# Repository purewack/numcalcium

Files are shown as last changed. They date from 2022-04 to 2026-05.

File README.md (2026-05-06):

# NumCalcium

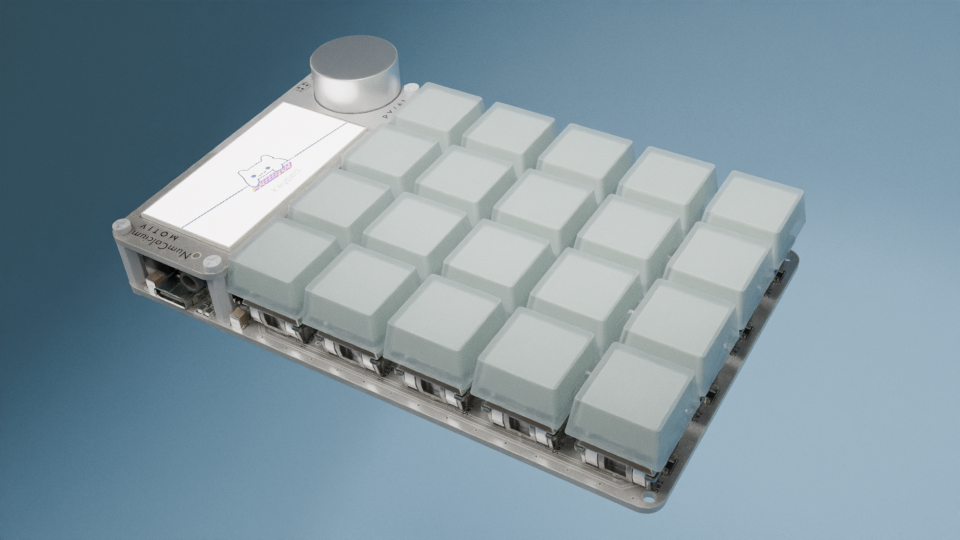
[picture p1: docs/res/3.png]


NumCalcium is a calculator-like USB + Bluetooth Numpad keyboard. This is the primary intended function, however, because it is powered by MicroPython, users are able to write their own programs for it.
There were a number of different hardware and software revision before I settled on a combination of an ESP32 S3 and MicroPython. It made so much sense for the applications that I wanted to achieve, and was far easier to get working than my previous attempts with STM32F103 and a custom system in C, more about the development history below if you're interested :)

## Installation

You can download the release binary and flash it using esptool.py or other compatible ESP32 flashing tools.
You can also build the sources and / or change any config here to suit your needs, then flash the resulting binary.

The recommended method is to use the Makefile in this repo, which in turn uses `Docker` to pull the specific `esp-idf` version to build `MicroPython` against.

Hold down the encoder button (ESP32 GP0 pin) and reset the device, then:

```bash
make gen-ulp all deploy
```

## Hardware

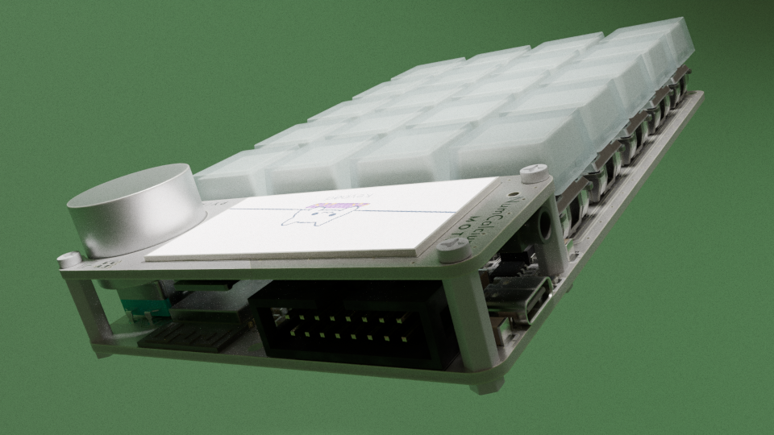
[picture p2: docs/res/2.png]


The hardware contains an ESP32 S3 module with integrated PSRAM, a color LCD (320*170 px, ST7789), a rotary encoder, 20 mechanical switch buttons, SD card slot, USB (2.0) C port, Headphone jack, a buzzer, and exposed GPIO using an IDC connector.

### Pinout
The IDC connector can be used to plug in external hardware in three ways:
- using jumper wires onto a breadboard
- using a dedicated IDC cable 
- using the port to plug in custom PCBs

The last option is encouraged to develop standalone daughter boards with your custom hardware, including driver code, which can be stored on a flash chip located on the daughter board, and have NumCalcium read it and execute the code!

```
BACK VIEW - TOP

                TOP OF IDC CONNECTOR
[GND,   VBAT,   SDA/TX1, SCL/RX1, TX0,  RX0, GND, VCC]
[GP8,   GP7,    GP6,     GP5,     GP4,  GP3, GP2, GP1]

BACK VIEW - BOTTOM OF BOARD
```

The rotary encoder button is connected to GP0, which allows entering flash mode for firmware updates. The button is also monitored and treated separately from the keys as this button is intended to return to the main app switcher, [described in detail on its own repo.](https://github.com/purewack/numcalcium-apps.git)

The device has a built in li-ion battery charger and voltage regulator, so you can power the whole unit off a 18650 cell, and charge it while using it. The regulator + charger combo has been configured in such a way to provide enough current for charging and system demands.

There is an additional low power regulator designed to be always on, to keep the ESP32 powered during deep-sleep. The ESP32 can control the main regulator and turn it off to power down all other components on the board, except itself. By doing this, the board can have peripherals plugged in to the IDC port, but they will not drain the battery, as the regulator will disable VCC and another transistor will cut VBAT to the IDC port, which normally would be connected directly to the 18650 cell.

<ins>**Warning:**</ins>

The VBAT, as mentioned above, is connected to the positive terminal of the 18650 battery cell through a MOSFET, no other protection is provided from shorting the pin to ground, so caution must be taken as these cells can discharge a lot of current at once very quickly, most likely damaging the transistor before any real harm is done elsewhere, regardless caution is to be taken when operating near this pin!

The headphone jack is connected to the ESP32 via stereo RC filters, for crude PDM audio, which is experimental as the performance hit of the MicroPython interpreter has an impact on the scheduling of audio buffers at the time of writing.

The buzzer is a piezo element which can be used for 'beeps and boops' for feedback purposes when writing your own apps. Its also quite good at playing chiptunes ;)

The SD card slot and LCD screen are on the same SPI bus so it is advised to write code around this limitation in mind, avoiding using threads to address the screen and card at the same time to avoid data corruption and unwanted side effects.

The LCD is connected to SPI3 Bus, leaving SPI2 available to users on the IDC port.

The IDC port exposes two UART pairs, and I2C pins on the same pins which are used by 'cartridge' PCB featuring flash chips with driver code, allowing the board to setup the pins and further communication as needed.
The RX0 TX0 pair is permanently mapped to output `stdout` for developing applications which use USB, allowing users to still see debugging output on their console using UART converters.

There are addressable LEDs under each key and on the front next to the LCD. with give more options for UI UX design by for example highlighting keys that do something in a certain mode.

## Software

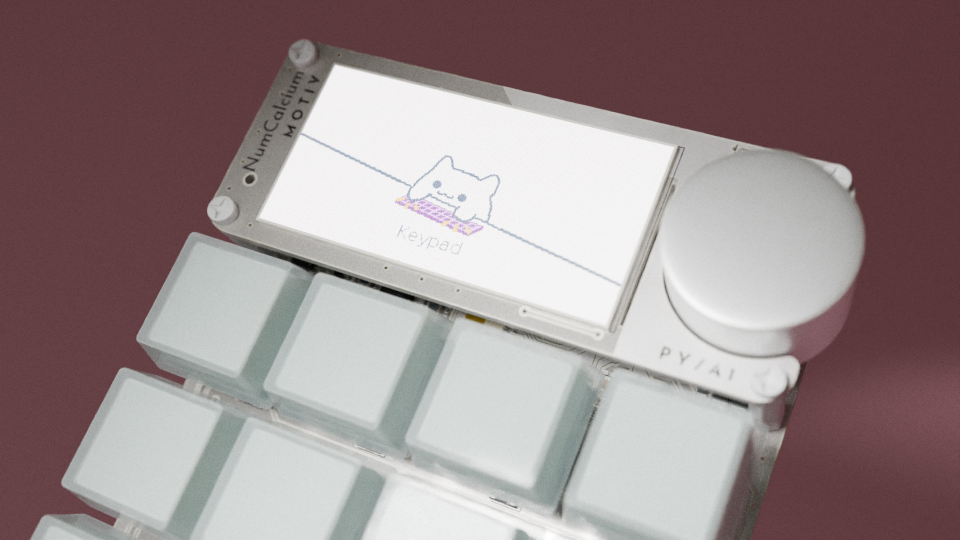
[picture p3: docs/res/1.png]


The main module which bundles all new and useful functionality compared to base MicroPython is `numcalc`.

This module contains classes making setting up common operations and pin assignments easier, specifically:
- interacting with the LCD
- LCD backlight adjustment
- a class specifically configuring the SD card slot
- buzzer tone control, 
- keypad input reading
- encoder turns and clicks
- LED control by obfuscating the neopixel class setup
- cartridge code loading and burning
- headphone PDM buffered audio streaming
- lcd BMP image parsing, framebuffer ready

> [class LCD() docs](docs/lcd.md)

> [class Keys() docs](docs/keys.md)

> [other `numcalc` functions docs](docs/other.md)

## Build and development

- Build and flash main firmware:

        make all
        make deploy

- Build and flash firmware with no modules, just c drivers:

        make firmware-no-freeze
        make deploy-no-freeze

- Build ULP code:

        make gen-ulp

- Build font file:
        make gen-font

- Update pin definitions:
        make gen-pins

# Devlog

I have included a development history going back through different [hardware designs and software paradigms.](devlog/HISTORY.md)

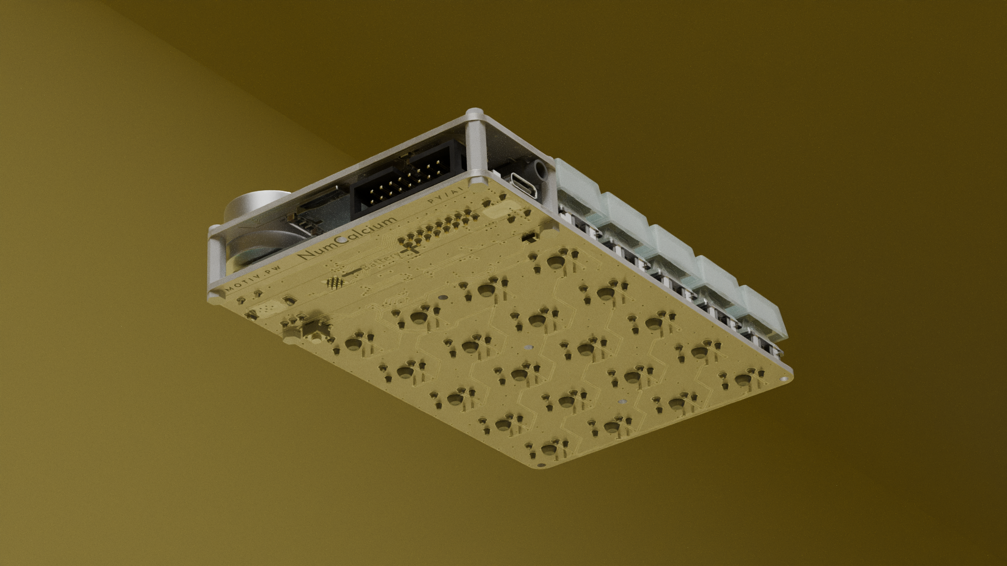
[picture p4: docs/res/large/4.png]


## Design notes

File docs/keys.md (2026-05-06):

# Keys Class Reference

The `Keys` class in `software-pya1/modules/__keys.py` provides access to the Numcalcium button matrix and encoder input. It is backed by an ESP32 ULP program that scans keys continuously, including during deep sleep, and stores press/release events in buffered state registers.

## Hardware

The keys are divided into groups of 3, reading from bottom to top and from left to right, giving 7 groups, with the last one having 2 keys.

The ULP manages the input and output states of only 4 pins to read 20 keys, multiplexing pin functions to drive a shift register on board driving each group one by one and reading each group state, accumulating results over the scanning period and placing the results in the buffered register, which the Keys class has access to via `mem32`.

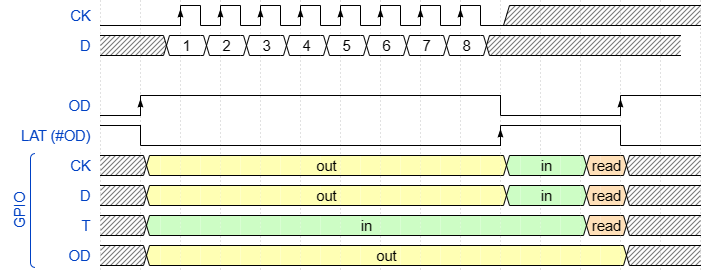
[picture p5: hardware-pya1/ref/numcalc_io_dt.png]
io timing


## Overview

- The ULP scans all physical keys and the rotary encoder.
- Key press and release events are buffered until explicitly cleared.
- Encoder turns and the encoder "home" click are also managed by the ULP.
- Raw read methods return current hardware state without clearing buffered events.

## Key encoding and mapping

Keys are represented as bits within a 20-bit integer.

- Each key corresponds to one bit.
- Bits are ordered from bottom-to-top, left-to-right.
- A set bit indicates the key has been pressed or released, depending on the buffer.

The class exposes named key constants, for example:

- `Keys.SHIFT`
- `Keys.DOT`
- `Keys.N0` through `Keys.N9`
- `Keys.F1`, `Keys.F2`, `Keys.F3`
- `Keys.A`, `Keys.B`, `Keys.C`, `Keys.D`, `Keys.E`

Alias names are also available for readability:

- `Keys.KEY_SHIFT`
- `Keys.KEY_DOT`
- `Keys.KEY_0` through `Keys.KEY_9`
- `Keys.KEY_F1`, `Keys.KEY_F2`, `Keys.KEY_F3`
- `Keys.KEY_SIDE_A` through `Keys.KEY_SIDE_E`

## ULP-managed buffering

The ULP keeps two buffered registers:

- `bdown` stores keys that have been pressed down.
- `bup` stores keys that have been released.

Buffer state is preserved across normal operation and deep sleep, allowing the application to read events later without missing input.

### Down and up queries

- `keys.isDown(key, reset=False)` returns whether the specified key is recorded as down.
- `keys.isUp(key, reset=False)` returns whether the specified key is recorded as up.

Both methods support an optional `reset=True` to clear the buffer bit for that key.

### Batch reads

- `keys.getAllDown()` returns a list of all keys currently buffered as down, then clears that buffer.
- `keys.getAllUp()` returns a list of all keys currently buffered as up, then clears that buffer.
- `keys.getNextDown()` returns the next buffered down key and clears it.
- `keys.getNextUp()` returns the next buffered up key and clears it.

### Clearing

- `keys.clearDown(key)` clears a single down bit.
- `keys.clearUp(key)` clears a single up bit.
- `keys.clearAllDown()` clears all down events.
- `keys.clearAllUp()` clears all up events.
- `keys.clearAll()` clears both up/down buffers and resets turn counts.

## Encoder support

Encoder movement and clicks are handled by the same ULP process.

- `keys.raw_turns()` returns the current raw encoder turn count.
- `keys.turns(invert=False)` reads and clears the turn counter.
- `keys.raw_home()` returns the current raw encoder click state.

### Home button behavior

The encoder click is treated specially as a "home" button, because its primary role is to return to the app launcher.

- `keys.shouldHome(value=None)` reads or writes the buffered home request flag.
- `keys.wasHomeRequested()` returns `True` if the home button was pressed, and clears the buffered state.

The internal `bhome` register is used to preserve the encoder click state until the main application consumes it.

## Raw state access

Raw read methods allow polling of the current hardware state without affecting buffered event registers:

- `keys.raw()` returns the current scanned key matrix value from `bscan`.
- `keys.raw_home()` returns the raw encoder click state.
- `keys.raw_turns()` returns the current encoder turn count.

These raw methods are useful for diagnostics and immediate state monitoring while keeping buffered press/release history intact.

## Initialization and driver loading

When a `Keys` object is constructed, it:

1. creates an `esp32.ULP_RV()` instance,
2. loads the ULP binary from `__ulpio`, and
3. starts the ULP program.

An optional scan period may be provided to `Keys(period)` to adjust the ULP wakeup interval.

## Example Usage

```python
from __keys import Keys

keys = Keys()

if keys.isDown(Keys.KEY_1, reset=True):
    print("Key 1 pressed")

turns = keys.turns()
if turns != 0:
    print("Encoder moved", turns)

if keys.wasHomeRequested():
    print("Home button clicked")

print("raw key bits", hex(keys.raw()))
```

## Notes

- The ULP scans keys even while the main CPU is asleep, making input reliable across sleep cycles.
- Press/release events are buffered independently from raw state reads.
- The encoder click is buffered as a home event rather than a normal key event.
- Clearing buffered values is explicit; raw reads do not consume events.

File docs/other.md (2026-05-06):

# Other Numcalcium Module Features

This document covers the remaining minor `numcalc` module components: module-level control functions, the `DAC` helper class, LED helpers, and the `Battery` utility.

## Top-Level Control Functions

### `shutdown()`

Shuts down the device cleanly by:

- clearing all NeoPixel LEDs with `clearLeds()`
- entering low-power sleep via `__sleep.enterLowPowerSleep()`

This is the recommended way to put the device into deep power-save mode.

### `runFromCartridge()`

Runs code stored on the external cartridge by delegating to `__cartridge.run()`.

### `burnToCartridge(data)`

Writes `data` to the cartridge using `__cartridge.burn(data)` and then verifies the burn with `__cartridge.check()`.

If the check fails, it raises an exception:

```python
raise Exception('Error during burning, check wiring and chip')
```

## `DAC` Class

The `DAC` class in `software-pya1/modules/numcalc.py` is a thin wrapper around the board-specific audio DAC implementation.

```python
class DAC(_board.DAC):
    pass
```

On this board, the actual audio driver is implemented in C in `software-pya1/cmodules/board_dac.c`.
That module exposes a Sigma-Delta audio class that is used by `_board.DAC`, so `numcalc.DAC` is effectively the Python entry point to the native audio driver.

### Board C module details

- The C implementation lives in `software-pya1/cmodules/board_dac.c`.
- It defines a `SigmaDelta` type with a constructor that accepts a buffer, a callback, and optional output pin configuration.
- The C driver supports single or dual buffer audio streaming and schedules callbacks when half or all samples have been consumed.
- It exposes `deinit()`, `pause()`, and `resume()` methods for managing playback.

### Typical usage

Examples in the repository show audio playback using `numcalc.DAC` with a buffer and a callback:

```python
import numcalc

sdm = numcalc.DAC(buffer_a, buffer_callback)
```

or with explicit output pins:

```python
sdm = numcalc.DAC(buffer_a, buffer_callback, [machine.Pin.board.A_OUT_L, machine.Pin.board.A_OUT_R])
```

A tuple of two buffers may also be passed for ping-pong streaming.

## LED Helper Functions

The module exposes simple NeoPixel-based LED control helpers backed by a `NeoPixel` object attached to `machine.Pin.board.LEDS`.

### `clearLeds()`

Turns all LEDs off and writes the change immediately.

### `statusLed(r, g, b)`

Sets LED index `0` to the provided RGB color and updates the strip.

This is usually used for a status indicator separate from the key LEDs.

### `led(keyNumber, r, g, b)`

Sets the LED for a given key index.

- `keyNumber` is mapped to NeoPixel index `keyNumber + 1`
- the first LED (`index 0`) is reserved for status

Example:

```python
numcalc.led(3, 255, 0, 0)
```

## `Battery` Class

The `Battery` class provides information about the battery and USB charge state.

### Initialization

On construction, `Battery()` initializes:

- `self.vbat` as an ADC on `machine.Pin.board.VBAT_MON`
- `self.vbus` as the charge-state pin `machine.Pin.board.CHR_STATE`
- `self.DIFF_THRESH = 0.05`

### `present()`

Returns `True` when a valid battery voltage is present.

In practice, it calls `self.voltage()` and interprets a non-zero voltage reading as present.

### `isAC()`

Reads the charger state pin four times with short delays and returns a boolean indicating whether external power is present.

### `voltage()`

Samples the battery voltage four times and computes the average.

- reads `self.vbat.read_uv()`
- converts microvolts to volts
- doubles the measured value to account for the voltage divider
- rejects the reading if the sample difference exceeds `DIFF_THRESH`

Returns `0` if the readings are inconsistent, otherwise returns the averaged voltage.

### `level()`

Converts the measured battery voltage into a fractional state-of-charge value between `0.0` and `1.0`.

- `low = 3.0`
- `high = 4.2`

The result is clamped to a minimum of `0`.

## `tone()` Function

Provides buzzer output using PWM on `machine.Pin.board.BUZZER`.

### Usage

- `tone('c4', velocity)` plays a note name with an optional velocity.
- `tone(midi_number, velocity)` plays a MIDI note number.
- `tone(None)` stops the buzzer by setting duty to `0`.

Note handling uses a standard 12-tone formula:

```python
freq = int(pow(2, (midi - 69) / 12) * 440)
```

Velocity is scaled by `>> 1` before it is applied to PWM duty.

## Notes

- `DAC` is a convenience alias for the board's DAC implementation.
- `Battery` is primarily a read-only helper; it does not control charging.
- `shutdown()` is the safe way to transition the device into its low-power sleep state.
- LED helpers always call `__neo.write()` so changes appear immediately.

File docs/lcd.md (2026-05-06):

# LCD Class Reference

The `LCD` class in `software-pya1/modules/numcalc.py` provides a high-level interface for the Numcalcium display. It extends the board-specific `_board.Terminal` implementation and adds convenience methods for drawing, text rendering, color conversion, canvas support, custom fonts, and backlight control.

## Key Features

- 320x170 display resolution (`LCD.WIDTH`, `LCD.HEIGHT`)
- Built-in 16-bit RGB565 color constants and helpers
- Text rendering with cursor control and scaling
- Canvas creation for off-screen drawing and partial updates
- Bitmap support and BMP loading
- Custom font loading from generated font modules
- Backlight brightness control
- Pixel plotting, area fill, and Bresenham-style line drawing

## Constants

The `LCD` class exposes common color constants:

- `LCD.RED`
- `LCD.GREEN`
- `LCD.BLUE`
- `LCD.PURPLE`
- `LCD.YELLOW`
- `LCD.CYAN`
- `LCD.BLACK`
- `LCD.WHITE`
- `LCD.GRAY`

It also includes display dimensions:

- `LCD.WIDTH = 320`
- `LCD.HEIGHT = 170`

## Initialization

Create the LCD object with:

```python
from numcalc import LCD
lcd = LCD()
```

The constructor resets the display and sets the default backlight brightness to a mid-level value.

## Drawing and Display Methods

### Clearing and background

- `lcd.clear()` clears the display and resets the cursor to `(0, 0)`.
- `lcd.fill(x, y, w, h, color)` fills a rectangle.
- `lcd.plot(x, y, color)` plots a single pixel.
- `lcd.line(x, y, x2, y2, color)` draws a line.

The `color` argument accepts:

- an integer RGB565 value,
- an HTML string like `"#ff0000"`, or
- an RGB tuple like `(255, 0, 0)`.

### Bitmaps and canvas

- `lcd.createCanvas()` allocates an off-screen canvas buffer for full-screen drawing.
- `lcd.update(x, y, w, h)` updates the display from the canvas.
- `lcd.buffer(buf, x, y, width, height)` writes raw framebuffer data.
- `lcd.loadBMP(file, headerOnly=False)` loads BMP image data from a file.
- `lcd.bitmap(x, y, image, scale=1)` draws a bitmap, with integer or float scaling.

### Text and cursor control

- `lcd.print(*args)` writes text to the display.
- `lcd.cursor(x, y, pixels=False, bottom=False)` can read or set the cursor position.
- `lcd.scale(value)` changes the text scale.
- `lcd.measure_text(text, pixels=False)` returns text size in character cells or pixels.

The cursor API supports both raw text coordinates and pixel coordinates via `pixels=True`.
It also supports a `bottom=True` mode for bottom-aligned coordinate translation.

### Colors and display options

- `lcd.background(color)` sets the background color.
- `lcd.foreground(color)` or `lcd.color(color)` sets the text/foreground color.
- `lcd.bg(color)` is an alias for `lcd.background(color)`.
- `lcd.invert(state)` enables or disables display inversion.
- `lcd.options(...)` accepts many display options and normalizes color inputs.

### Backlight

- `lcd.setBacklight(brightness)` sets brightness from `0` to `127`.

## Custom Font Support

The LCD supports loading external font modules that define:

- `data['width']`
- `data['height']`
- `data['count']`
- `data['name']`
- `data['data']`

A font module is loaded by passing it to `lcd.options(font=font_module)`.
When a font is unloaded with `lcd.options(font=None)`, the display returns to the default built-in font.

### Generating custom fonts with `make gen-font`

The repository includes a `Makefile` target for generating font assets:

```make
make gen-font
```

This target does the following:

1. Ensures `software-pya1/generated/` exists.
2. Creates the `software-pya1/fonts/$(FONT)` font directory.
3. Runs `software-pya1/generators/font.py` to build font files from the font PNG.
4. Produces generated Python font modules named `font_<name>.py` in `software-pya1/generated`.
5. Compiles each generated font module to MicroPython bytecode with `mpy-cross`.

The default font configuration in `Makefile` is:

- `FONT = gohu13`
- `FONT_CHAR_COUNT = 96`

### Using a generated font

After generating fonts, import the font module and load it into the LCD:

```python
import font_gohu13
from numcalc import LCD

lcd = LCD()
lcd.options(font=font_gohu13)
lcd.print("Hello custom font")
```

Once loaded, the LCD uses the generated font dimensions for text rendering and cursor layout.

## Example Usage

```python
from numcalc import LCD
import font_gohu13

lcd = LCD()
lcd.clear()
lcd.background("#000000")
lcd.foreground((255, 255, 255))
lcd.options(font=font_gohu13)
lcd.scale(2)
lcd.print("Numcalcium LCD")

canvas = lcd.createCanvas()
# draw to canvas with lcd.plot, lcd.fill, lcd.line, etc.
lcd.update()
```

## Notes

- `LCD.createCanvas()` allocates a full-screen off-screen buffer that can be updated incrementally.
- `lcd.scale()` changes the effective drawing grid and text cell size.
- `lcd.htmlTo565()` and `lcd.rgbTo565()` are available for converting standard color formats.

This document describes the high-level `LCD` API and how to generate and load custom fonts for Numcalcium applications.

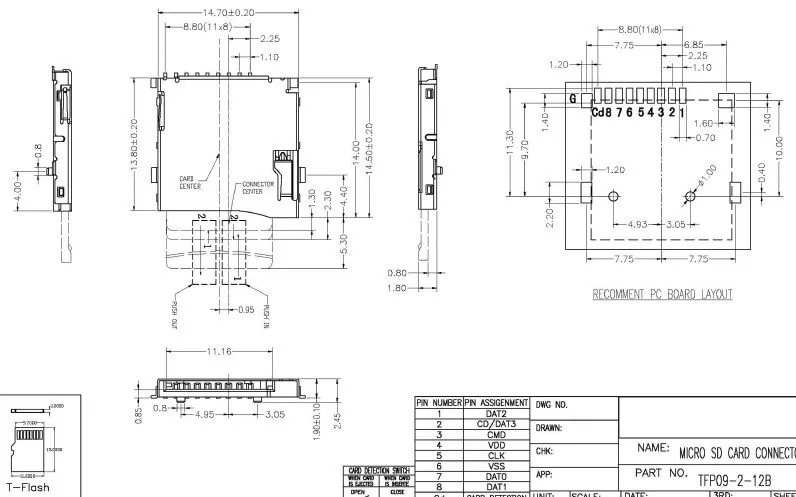
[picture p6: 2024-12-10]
hardware-pya1/ref/7176157e-b5ed-4b9a-86a6-ef39661fa425.png

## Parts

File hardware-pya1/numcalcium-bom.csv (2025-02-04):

Reference | Value | Footprint
BT1 | Battery | footprints:LiIon18650
BZ1 | Buzzer | Buzzer_Beeper:MagneticBuzzer_CUI_CMT-8504-100-SMT
C1 | 100uF | Capacitor_SMD:C_1210_3225Metric
C2 | 220u | Capacitor_SMD:C_2220_5750Metric
C3 | 47u | Capacitor_SMD:C_1210_3225Metric_Pad1.33x2.70mm_HandSolder
C4 | 1u | Capacitor_SMD:C_0805_2012Metric
C5 | 22u | Capacitor_SMD:C_1210_3225Metric
C6 | 220u | Capacitor_SMD:C_2220_5750Metric
C7 | 1u | Capacitor_SMD:C_1206_3216Metric
C8 | 100n | Capacitor_SMD:C_0805_2012Metric
C9 | 1u | Capacitor_SMD:C_0805_2012Metric
C10 | 1u | Capacitor_SMD:C_0805_2012Metric
C11 | 100n | Capacitor_SMD:C_0805_2012Metric
C12 | 22u | Capacitor_SMD:C_1210_3225Metric
C13 | 22u | Capacitor_SMD:C_1210_3225Metric
C14 | 1u | Capacitor_SMD:C_0805_2012Metric_Pad1.18x1.45mm_HandSolder
C15 | 10u | Capacitor_SMD:C_0805_2012Metric
C16 | 1u | Capacitor_SMD:C_0805_2012Metric_Pad1.18x1.45mm_HandSolder
C17 | 1u | Capacitor_SMD:C_0805_2012Metric_Pad1.18x1.45mm_HandSolder
C18 | 1u | Capacitor_SMD:C_0805_2012Metric_Pad1.18x1.45mm_HandSolder
C19 | 1u | Capacitor_SMD:C_0805_2012Metric_Pad1.18x1.45mm_HandSolder
C20 | 220n | Capacitor_SMD:C_0805_2012Metric
C21 | 220n | Capacitor_SMD:C_0805_2012Metric
C22 | 100u | Capacitor_SMD:C_1210_3225Metric_Pad1.33x2.70mm_HandSolder
C23 | 2u2 | Capacitor_SMD:C_0805_2012Metric
D1 | D | Diode_SMD:D_1206_3216Metric
D2 | D | Diode_SMD:D_1206_3216Metric
D3 | D | Diode_SMD:D_1206_3216Metric
D4 | D | Diode_SMD:D_1206_3216Metric
D5 | D | Diode_SMD:D_1206_3216Metric
D6 | D | Diode_SMD:D_1206_3216Metric
D7 | D | Diode_SMD:D_1206_3216Metric
D8 | D | Diode_SMD:D_1206_3216Metric
D9 | D | Diode_SMD:D_1206_3216Metric
D10 | D | Diode_SMD:D_1206_3216Metric
D11 | D | Diode_SMD:D_1206_3216Metric
D12 | D | Diode_SMD:D_1206_3216Metric
D13 | D | Diode_SMD:D_1206_3216Metric
D14 | D | Diode_SMD:D_1206_3216Metric
D15 | D | Diode_SMD:D_1206_3216Metric
D16 | D | Diode_SMD:D_1206_3216Metric
D17 | D | Diode_SMD:D_1206_3216Metric
D18 | D | Diode_SMD:D_1206_3216Metric
D19 | D | Diode_SMD:D_1206_3216Metric
D20 | D | Diode_SMD:D_1206_3216Metric
D21 | WS2812B-2020 | LED_SMD:LED_WS2812B-2020_PLCC4_2.0x2.0mm
D22 | WS2812B-2020 | LED_SMD:LED_WS2812B-2020_PLCC4_2.0x2.0mm
D23 | WS2812B-2020 | LED_SMD:LED_WS2812B-2020_PLCC4_2.0x2.0mm
D24 | WS2812B-2020 | LED_SMD:LED_WS2812B-2020_PLCC4_2.0x2.0mm
D25 | WS2812B-2020 | LED_SMD:LED_WS2812B-2020_PLCC4_2.0x2.0mm
D26 | WS2812B-2020 | LED_SMD:LED_WS2812B-2020_PLCC4_2.0x2.0mm
D27 | WS2812B-2020 | LED_SMD:LED_WS2812B-2020_PLCC4_2.0x2.0mm
D28 | WS2812B-2020 | LED_SMD:LED_WS2812B-2020_PLCC4_2.0x2.0mm
D29 | WS2812B-2020 | LED_SMD:LED_WS2812B-2020_PLCC4_2.0x2.0mm
D30 | WS2812B-2020 | LED_SMD:LED_WS2812B-2020_PLCC4_2.0x2.0mm
D31 | WS2812B-2020 | LED_SMD:LED_WS2812B-2020_PLCC4_2.0x2.0mm
D32 | WS2812B-2020 | LED_SMD:LED_WS2812B-2020_PLCC4_2.0x2.0mm
D33 | WS2812B-2020 | LED_SMD:LED_WS2812B-2020_PLCC4_2.0x2.0mm
D34 | WS2812B-2020 | LED_SMD:LED_WS2812B-2020_PLCC4_2.0x2.0mm
D35 | WS2812B-2020 | LED_SMD:LED_WS2812B-2020_PLCC4_2.0x2.0mm
D36 | WS2812B-2020 | LED_SMD:LED_WS2812B-2020_PLCC4_2.0x2.0mm
D37 | WS2812B-2020 | LED_SMD:LED_WS2812B-2020_PLCC4_2.0x2.0mm
D38 | WS2812B-2020 | LED_SMD:LED_WS2812B-2020_PLCC4_2.0x2.0mm
D39 | WS2812B-2020 | LED_SMD:LED_WS2812B-2020_PLCC4_2.0x2.0mm
D40 | WS2812B-2020 | LED_SMD:LED_WS2812B-2020_PLCC4_2.0x2.0mm
D41 | WS2812B-2020 | LED_SMD:LED_WS2812B-2020_PLCC4_2.0x2.0mm
D42 | D | Diode_SMD:D_1206_3216Metric
D43 | SS32 | Diode_SMD:D_SMA
D44 | D | Diode_SMD:D_1206_3216Metric
D45 | D | Diode_SMD:D_1206_3216Metric
D46 | D | Diode_SMD:D_1206_3216Metric
D47 | BAT_REV | Diode_SMD:D_1206_3216Metric
J1 | Conn_01x14_Socket | Connector_FFC-FPC:Hirose_FH12-14S-0.5SH_1x14-1MP_P0.50mm_Horizontal
J2 | Conn_01x14_Socket | Connector_FFC-FPC:Hirose_FH12-14S-0.5SH_1x14-1MP_P0.50mm_Horizontal
J3 | LCD_socket | Connector_FFC-FPC:Hirose_FH12-30S-0.5SH_1x30-1MP_P0.50mm_Horizontal
J4 | Micro_SD_Card_Det2 | footprints:microSD_Short_1
J5 | AudioJack4 | footprints:Jack_3.5mm_PJ320D_Horizontal
J6 | USB_C_Receptacle_USB2.0_16P | Connector_USB:USB_C_Receptacle_GCT_USB4105-xx-A_16P_TopMnt_Horizontal
J7 | Conn_02x08_Odd_Even | footprints:IDC-Header_2x08_P2.54mm_Horizontal
L1 | 2u2 | Inductor_SMD:L_Chilisin_BMRA00050530
L2 | 470u | Inductor_SMD:L_1210_3225Metric
L3 | 470u | Inductor_SMD:L_1210_3225Metric
Q1 | AO3401A | Package_TO_SOT_SMD:SOT-23
Q2 | BSS138 | Package_TO_SOT_SMD:SOT-23
Q3 | AO3401A | Package_TO_SOT_SMD:SOT-23
Q5 | AO4953A | Package_SO:SOP-8_3.9x4.9mm_P1.27mm
Q6 | BSS138 | Package_TO_SOT_SMD:SOT-23
Q8 | BSS138 | Package_TO_SOT_SMD:SOT-23
Q9 | BSS138 | Package_TO_SOT_SMD:SOT-23
R1 | 33k | Resistor_SMD:R_0805_2012Metric_Pad1.20x1.40mm_HandSolder
R2 | 47 | Resistor_SMD:R_0805_2012Metric_Pad1.20x1.40mm_HandSolder
R3 | 1M | Resistor_SMD:R_0805_2012Metric_Pad1.20x1.40mm_HandSolder
R4 | 1k | Resistor_SMD:R_0805_2012Metric_Pad1.20x1.40mm_HandSolder
R5 | 33k | Resistor_SMD:R_0805_2012Metric_Pad1.20x1.40mm_HandSolder
R6 | 33k | Resistor_SMD:R_0805_2012Metric_Pad1.20x1.40mm_HandSolder
R7 | 1M | Resistor_SMD:R_0805_2012Metric_Pad1.20x1.40mm_HandSolder
R8 | 220k | Resistor_SMD:R_0805_2012Metric_Pad1.20x1.40mm_HandSolder
R9 | 47k | Resistor_SMD:R_0805_2012Metric_Pad1.20x1.40mm_HandSolder
R10 | 1M | Resistor_SMD:R_0805_2012Metric_Pad1.20x1.40mm_HandSolder
R12 | 470k | Resistor_SMD:R_0805_2012Metric_Pad1.20x1.40mm_HandSolder
R14 | 10k | Resistor_SMD:R_0805_2012Metric_Pad1.20x1.40mm_HandSolder
R15 | 100k | Resistor_SMD:R_0805_2012Metric_Pad1.20x1.40mm_HandSolder
R16 | 5k1 | Resistor_SMD:R_0805_2012Metric_Pad1.20x1.40mm_HandSolder
R17 | 5k1 | Resistor_SMD:R_0805_2012Metric_Pad1.20x1.40mm_HandSolder
R18 | 100k | Resistor_SMD:R_0805_2012Metric_Pad1.20x1.40mm_HandSolder
R19 | 100 | Resistor_SMD:R_0805_2012Metric_Pad1.20x1.40mm_HandSolder
R20 | 1k | Resistor_SMD:R_0805_2012Metric_Pad1.20x1.40mm_HandSolder
R21 | 47k | Resistor_SMD:R_0805_2012Metric_Pad1.20x1.40mm_HandSolder
R22 | 47k | Resistor_SMD:R_0805_2012Metric_Pad1.20x1.40mm_HandSolder
R23 | 47k | Resistor_SMD:R_0805_2012Metric_Pad1.20x1.40mm_HandSolder
R24 | 47k | Resistor_SMD:R_0805_2012Metric_Pad1.20x1.40mm_HandSolder
R25 | 47k | Resistor_SMD:R_0805_2012Metric_Pad1.20x1.40mm_HandSolder
R26 | 470k | Resistor_SMD:R_0805_2012Metric_Pad1.20x1.40mm_HandSolder
R27 | 1M | Resistor_SMD:R_0805_2012Metric_Pad1.20x1.40mm_HandSolder
R28 | 2k2 | Resistor_SMD:R_0805_2012Metric_Pad1.20x1.40mm_HandSolder
R29 | 2k2 | Resistor_SMD:R_0805_2012Metric_Pad1.20x1.40mm_HandSolder
SW1 | SW_Push | footprints:SW_Cherry_MX_1.00u_PCB
SW2 | SW_Push | footprints:SW_Cherry_MX_1.00u_PCB
SW3 | SW_Push | footprints:SW_Cherry_MX_1.00u_PCB
SW4 | SW_Push | footprints:SW_Cherry_MX_1.00u_PCB
SW5 | SW_Push | footprints:SW_Cherry_MX_1.00u_PCB
SW6 | SW_Push | footprints:SW_Cherry_MX_1.00u_PCB
SW7 | SW_Push | footprints:SW_Cherry_MX_1.00u_PCB
SW8 | SW_Push | footprints:SW_Cherry_MX_1.00u_PCB
SW9 | SW_Push | footprints:SW_Cherry_MX_1.00u_PCB
SW10 | SW_Push | footprints:SW_Cherry_MX_1.00u_PCB
SW11 | SW_Push | footprints:SW_Cherry_MX_1.00u_PCB
SW12 | SW_Push | footprints:SW_Cherry_MX_1.00u_PCB
SW13 | SW_Push | footprints:SW_Cherry_MX_1.00u_PCB
SW14 | SW_Push | footprints:SW_Cherry_MX_1.00u_PCB
SW15 | SW_Push | footprints:SW_Cherry_MX_1.00u_PCB
SW16 | SW_Push | footprints:SW_Cherry_MX_1.00u_PCB
SW17 | SW_Push | footprints:SW_Cherry_MX_1.00u_PCB
SW18 | SW_Push | footprints:SW_Cherry_MX_1.00u_PCB
SW19 | SW_Push | footprints:SW_Cherry_MX_1.00u_PCB
SW20 | SW_Push | footprints:SW_Cherry_MX_1.00u_PCB
SW21 | Encoder | footprints:RotaryEncoder_Alps_EC11E-Switch_Vertical_H20mm
SW22 | SW_Push | Button_Switch_SMD:SW_SPST_PTS647_Sx38
U1 | LTC4054 | Package_TO_SOT_SMD:TSOT-23-5
U2 | STI3411A | Package_TO_SOT_SMD:TSOT-23-5
U3 | 74HC595 | Package_SO:TSSOP-16_4.4x5mm_P0.65mm
U4 | ESP32-S3-WROOM-1 | footprints:ESP32-S3-WROOM-1-Compact-Court
U5 | XC6206PxxxMR | Package_TO_SOT_SMD:SOT-23-3

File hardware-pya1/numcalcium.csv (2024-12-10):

Id | Designator | Footprint | Quantity | Designation | Supplier and ref
1 | SW15,SW8,SW1,SW3,SW18,SW7,SW10,SW16,SW12,SW11,SW17,SW19,SW9,SW13,SW4,SW2,SW5,SW20,SW6,SW14 | Combo_MechanicalSwitch | 20 | SW_Push
2 | Q3,Q2,Q5 | SOT-23 | 3 | BSS138
3 | C2 | C_0805_2012Metric | 1 | 100n
4 | R13,R14 | R_0805_2012Metric_Pad1.20x1.40mm_HandSolder | 2 | 1M
5 | R3,R4 | R_0805_2012Metric_Pad1.20x1.40mm_HandSolder | 2 | 5k6
6 | R11,R2,R12,R6,R9,R1 | R_0805_2012Metric_Pad1.20x1.40mm_HandSolder | 6 | 100k
7 | R10 | R_0805_2012Metric_Pad1.20x1.40mm_HandSolder | 1 | 220k
8 | R15 | R_0805_2012Metric_Pad1.20x1.40mm_HandSolder | 1 | 10k
9 | R7 | R_0805_2012Metric_Pad1.20x1.40mm_HandSolder | 1 | 33k
10 | BZ1 | MagneticBuzzer_CUI_CMT-8504-100-SMT | 1 | Buzzer
11 | C3 | C_1210_3225Metric_Pad1.33x2.70mm_HandSolder | 1 | 22u
12 | D23,D22,D25,D26,D24,D1,D9,D18,D3,D4,D2,D12,D20,D15,D13,D8,D17,D14,D16,D11,D5,D19,D6,D7,D10 | D_0805_2012Metric_Pad1.15x1.40mm_HandSolder | 25 | D
13 | L1 | L_Chilisin_BMRA00050530 | 1 | 2u2
14 | R19,R8,R18,R20,R17 | R_0805_2012Metric_Pad1.20x1.40mm_HandSolder | 5 | 47k
15 | SW21 | RotaryEncoder_Alps_EC11E-Switch_Vertical_H20mm | 1 | Encoder
16 | C9 | C_0805_2012Metric_Pad1.18x1.45mm_HandSolder | 1 | 22u
17 | C4 | C_0805_2012Metric_Pad1.18x1.45mm_HandSolder | 1 | 10u
18 | C5,C8 | C_0805_2012Metric_Pad1.18x1.45mm_HandSolder | 2 | 1u
19 | C1 | C_1210_3225Metric_Pad1.33x2.70mm_HandSolder | 1 | 10u
20 | Q1 | SOIC-8_3.9x4.9mm_P1.27mm | 1 | Q_Dual_PMOS_S1G1S2G2D2D2D1D1
21 | D21 | R_0805_2012Metric_Pad1.20x1.40mm_HandSolder | 1 | BAT_REV
22 | R5 | R_0805_2012Metric_Pad1.20x1.40mm_HandSolder | 1 | 2k
23 | U5 | SOT-23-3 | 1 | XC6206PxxxMR
24 | C6 | R_1210_3225Metric_Pad1.30x2.65mm_HandSolder | 1 | 22u
25 | C7 | R_0805_2012Metric_Pad1.20x1.40mm_HandSolder | 1 | 100n
26 | J3 | PinSocket_1x12_P2.54mm_Vertical | 1 | SK_CART
27 | U1 | ESP32-WROOM-32-min | 1 | ESP32-WROOM-32D
28 | J1 | microSD_Short_1 | 1 | Micro_SD_Card_Det2
29 | J2 | Jack_3.5mm_PJ320D_Horizontal | 1 | AudioJack3
30 | R16 | R_0805_2012Metric_Pad1.20x1.40mm_HandSolder | 1 | 470k
31 | U4 | Texas_HSOP-8-1EP_3.9x4.9mm_P1.27mm_ThermalVias | 1 | ~
32 | U2 | SOIC-16_3.9x9.9mm_P1.27mm | 1 | 74HC595
33 | J4 | USB_C_Receptacle_GCT_USB4105-xx-A_16P_TopMnt_Horizontal | 1 | USB_C_Receptacle_USB2.0_16P
34 | U3 | ST7789 1.9inch module Display (BL_NO_HOLE) | 1 | ISP Display
35 | U6 | SOT-23-5_HandSoldering | 1 | ~
36 | BT1 | LiIon18650 | 1 | Battery

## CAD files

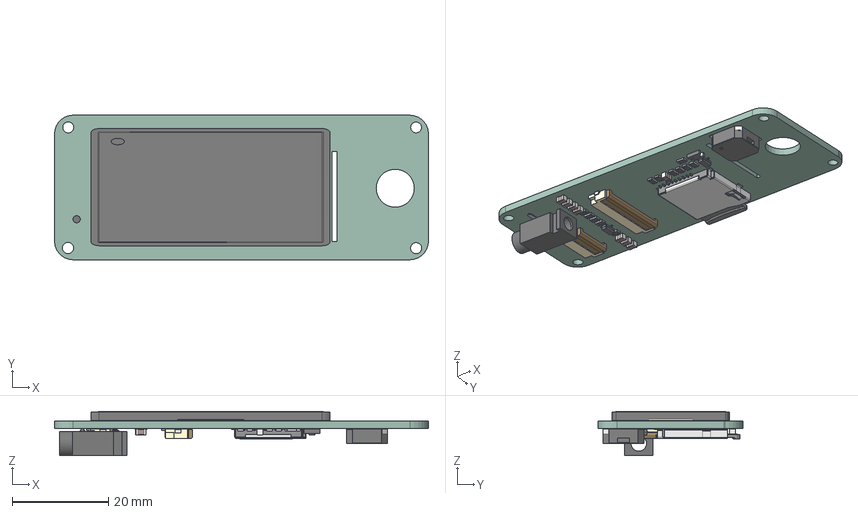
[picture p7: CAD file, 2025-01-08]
hardware-pya1/numcalcium-front.step
77.5 x 30.0 x 9.13 mm
Buzzer_Murata_PKMCS0909E4000_R1
R_0805_2012Metric x 12
C_0805_2012Metric x 8
SOT_23 x 2
MagneticBuzzer_Kobitone_254_EMB84Q_RO
Hirose_FH12_xxS_0_5SH_Parametric_v0_1 x 2
D_1206
Frame
MicroSD
Pin1
Pin2
Pin3
Pin4
Pin5
Pin6
Pin7
Pin8
Pin9
B
_autosave-numcalcium_PCB

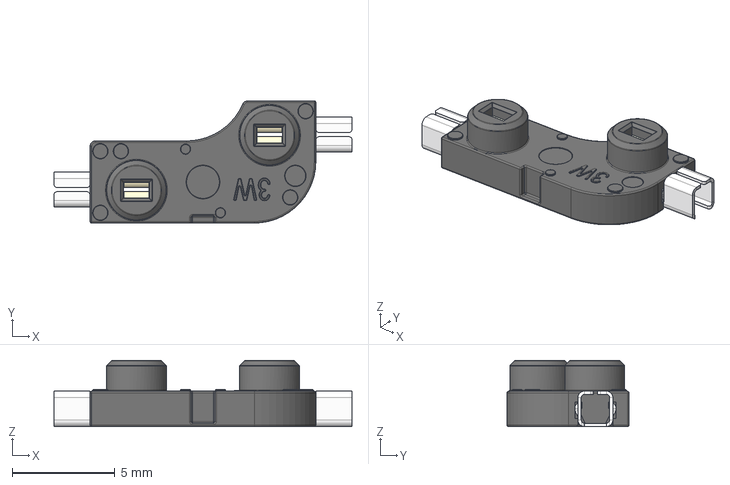
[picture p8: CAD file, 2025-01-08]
hardware-pya1/Kailh Hotswap MX v22.step
14.5 x 5.95 x 3.22 mm

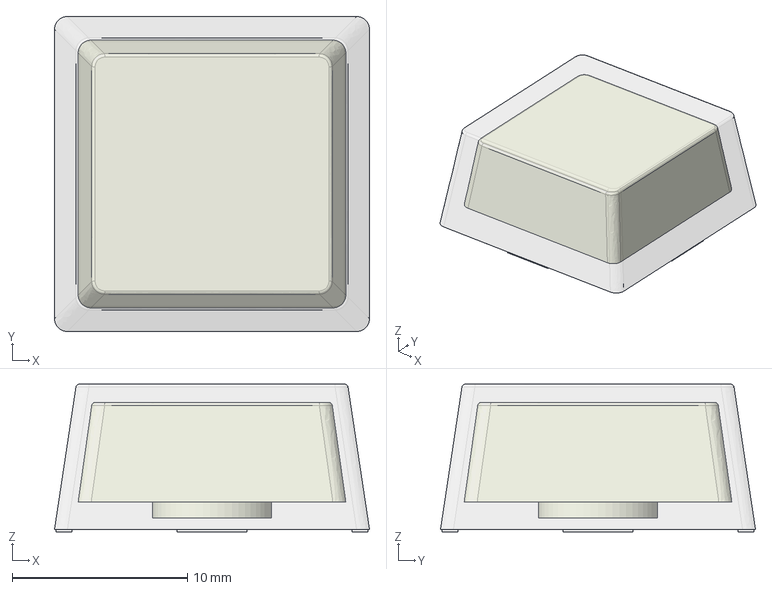
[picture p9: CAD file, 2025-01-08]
hardware-pya1/beschr. Kappe.step
18.0 x 18.0 x 8.45 mm
beschr. Kappe Abdeckung
beschr. Kappe Unterteil

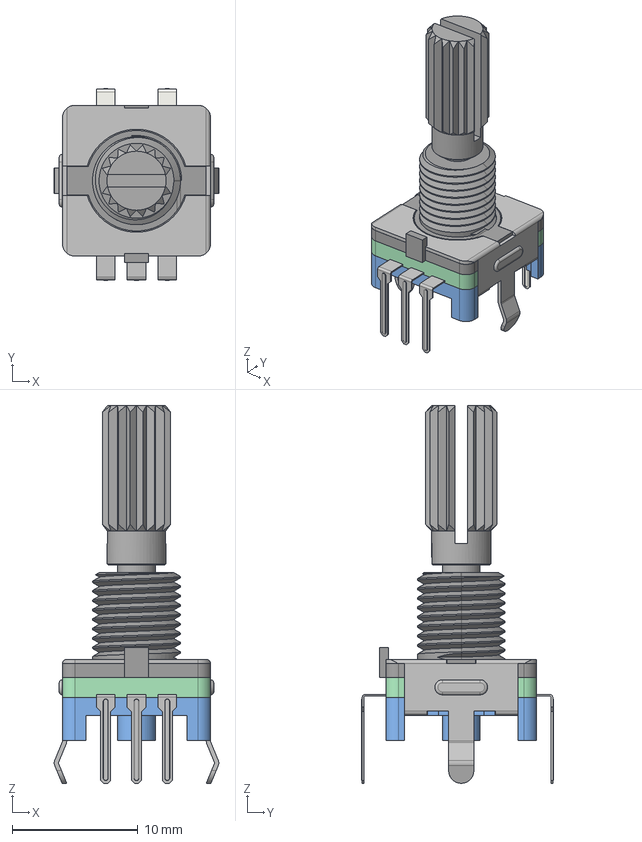
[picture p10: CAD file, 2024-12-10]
hardware-pya1/EC11_Rotary_Encoder_Switched.step
13.1 x 15.3 x 30.1 mm

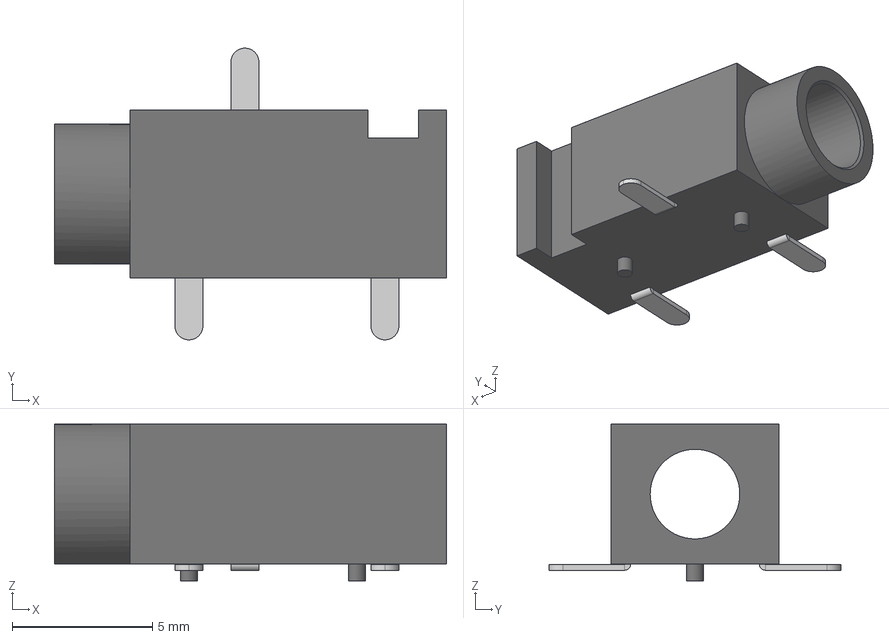
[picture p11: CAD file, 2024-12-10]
hardware-pya1/Jack_3.5mm_PJ320B_Horizontal.step
14.0 x 10.4 x 5.60 mm
Pads001

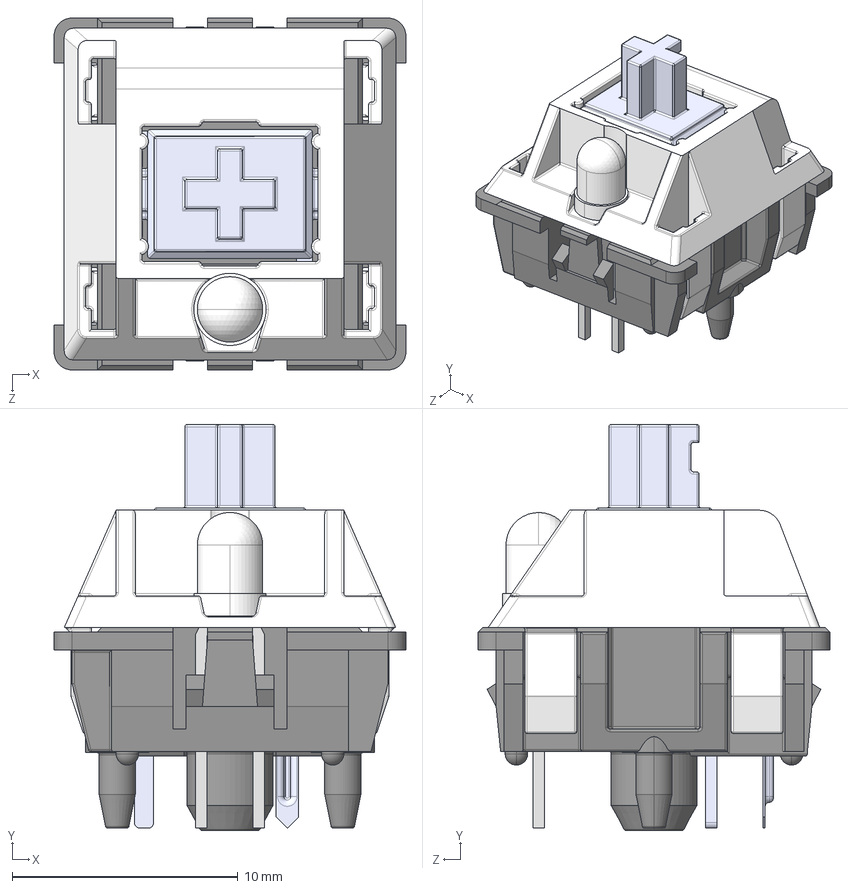
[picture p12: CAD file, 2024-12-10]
hardware-pya1/Cherry MX.STEP
15.6 x 18.0 x 15.6 mm
Bottom
Pulsador
Top
Pieza5^Cherry MX
Pin1
Pin2
Led 3mm_trans

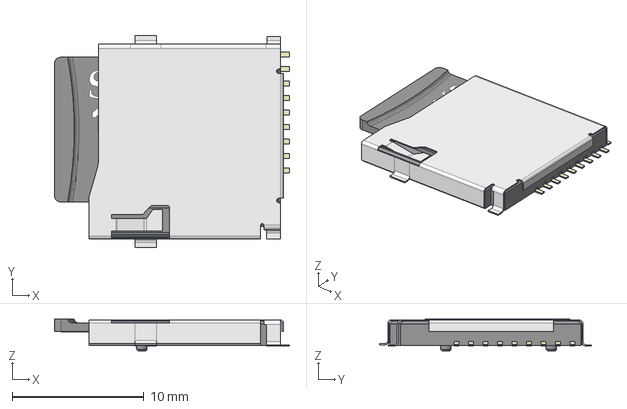
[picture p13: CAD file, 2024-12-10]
hardware-pya1/TF-01A.step
17.8 x 16.1 x 2.40 mm

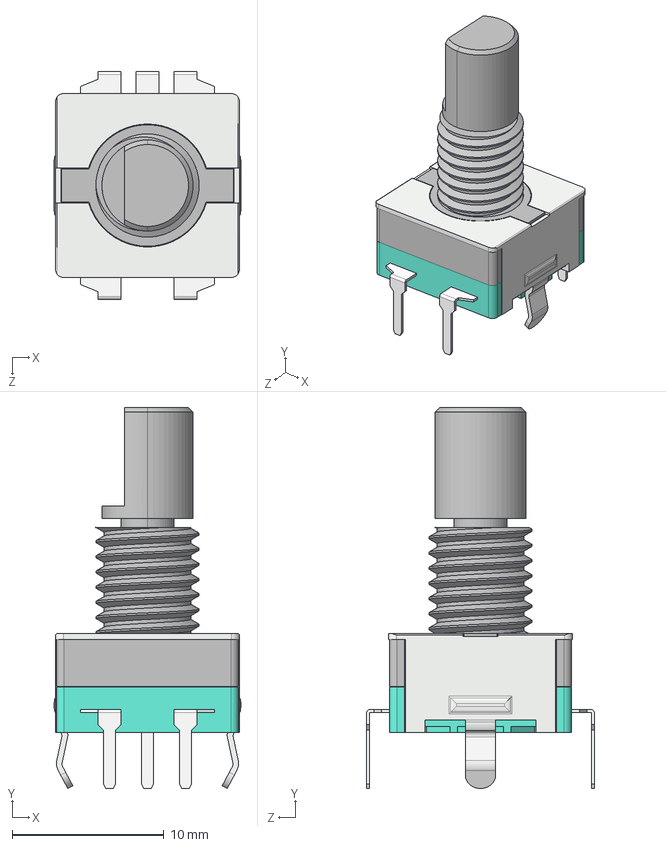
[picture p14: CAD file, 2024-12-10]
hardware-pya1/Ël__h.STEP
12.3 x 25.1 x 15.0 mm

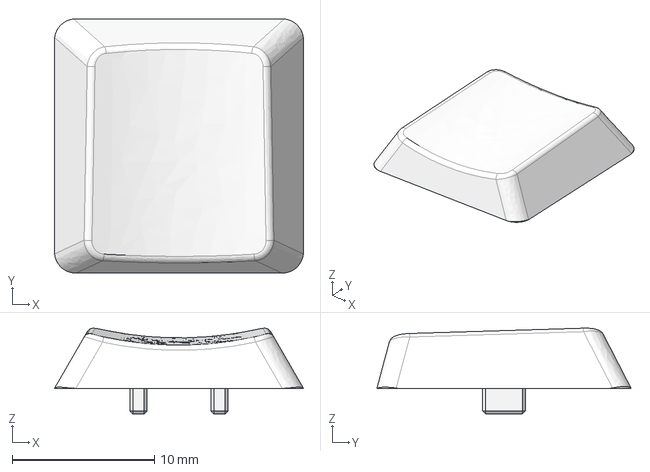
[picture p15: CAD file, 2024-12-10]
hardware-pya1/Kailh LP Choc PC Keycap.step
17.5 x 17.9 x 6.03 mm

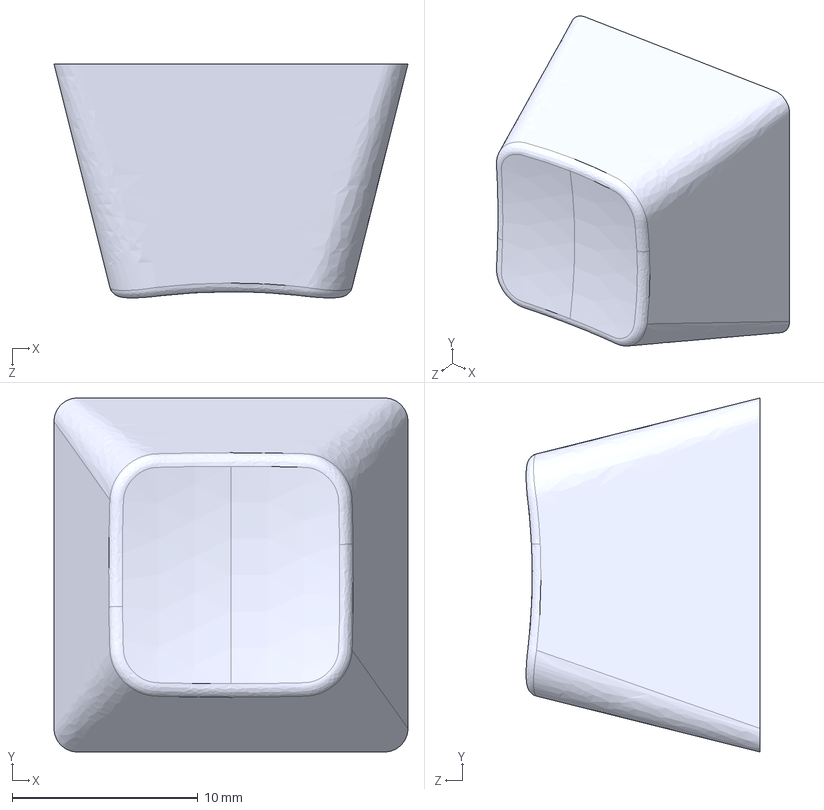
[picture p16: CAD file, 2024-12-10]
hardware-pya1/keycap_dsa_signatureplastics_r3.STEP
19.1 x 19.1 x 12.6 mm

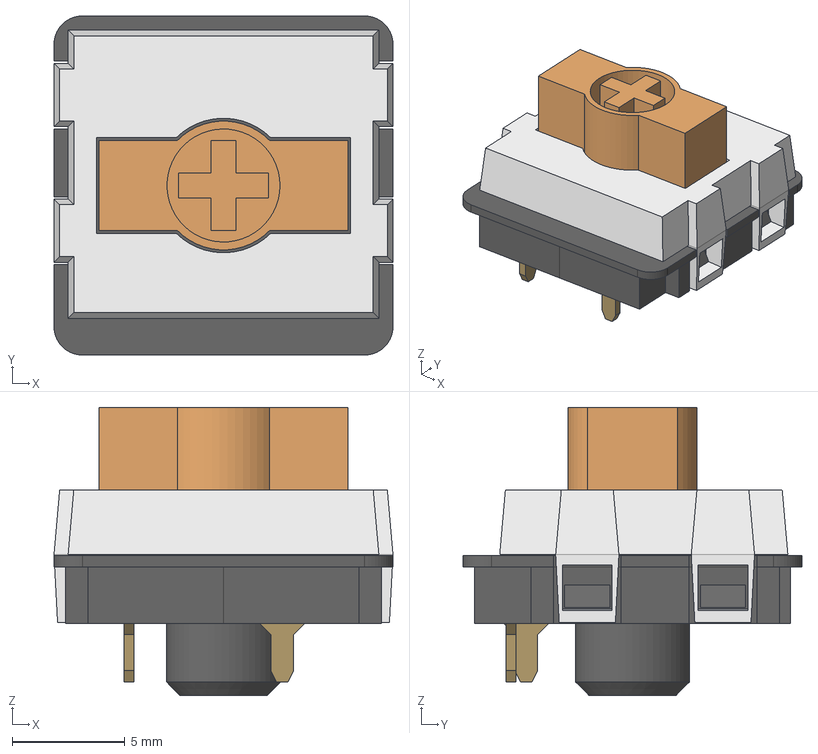
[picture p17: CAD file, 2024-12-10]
hardware-pya1/Gateron KS-33.step
15.0 x 15.0 x 12.8 mm
Base
Stem
Cap
PinA
PinB

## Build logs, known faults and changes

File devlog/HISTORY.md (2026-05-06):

# History

### Version 1

The first version for hardware and software was an STM32F103 core with a basic LCD in monochrome at 128x64 pixels. The STM32 was a good first candidate as it was cheap and relatively simple to just start writing some C code in the Arduino IDE. I wrote quite a few different apps and even a transistor latching power switch using the encoder switch turning on a MOSFET to provide power to the chip, which then could be turned off from software level by 'choking' the MOSFET gate (sometimes it could fail though, leaving the board in a wierd state)

Keyscanning was inspired by how (i think) the Nintendo DS did it, at least in software, meaning the key values for down and up presses of each key are stored as bits in two long binary numbers. The bits keep their state until the software that needs to read their state clears them, giving us buffered key input in a sense.

The STM32 did this here using interrupts and scanning each row on every interrupt, giving users access to the buffered key registers for use in the programs without actually reading or scanning the keys states manually.



As you can see, the times were rough and I had to develop this using an old arduino nano clone which I had previously shorted, so the chip is gone and I used the UART converter from this board to program the STM32 :/


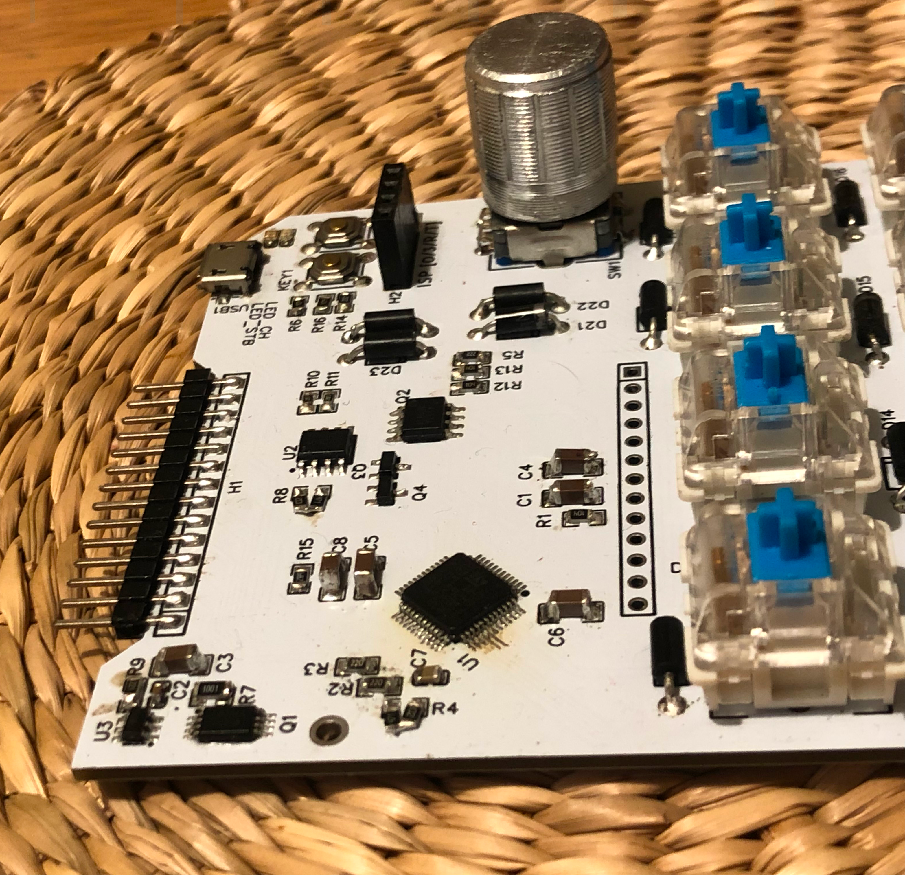
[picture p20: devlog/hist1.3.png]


### Version 2

The next version was on the same core as I had ambitions to keep the cost down to make it easier for DIY enthusiasts assembling their own boards. This time however I designed the board with more ideas revolving around making it easier to execute custom external code.

I has some success in doing this but the process was not very user friendly and I had fallen into a deep rabbit hole of trying to develop my own linker script to allow the external code to reference functions found in the flash, resembling something close to static linking against the binary found on the chip. This was a partial success, and partial because the memory limitations kicked in quick given the 64k flash space I had on this specific target chip.

I felt like upgrading to a beefier STM32 variant would be the way to go, but at this time esp8266 was really kicking off so I was exploring that for some time, but eventually dismissed it for not having native USB, something I felt was crucial for a device that is to behave like a keypad. 

I had actually abandoned the project for some time due to not being knowledgeable enough to know how to tie all these knots into one string, to form a device that is both user customizable and at the same time user friendly.



The board layout has become significantly more cramped since the last revision as I have included a lot more exposed IO inline with the new philosophy of user executable code and customization. I also added an SD card slot which later turned out could not be used at the same time as the GPIO on the ports as they shared the same pins, yet another reason to consider a different chip / design.

### Version 3

This is the first design with an ESP32 as I decided at this time that I do not need a USB really, I could do with just bluetooth, which the ESP32 had. 

At this time I also started leaning into MicroPython more and decided that I can experiment if this is possible at all either by writing esp-idf code or trying to get MicroPython to run with the key scanning interrupt hack.

This board however never made it into prototyping stage and was instead stuck in layout hell. I was trying to accommodate the cartridge pinout, a new color LCD and wifi/bluetooth antenna layout guides which recommended leaving some unpopulated space around the antenna.

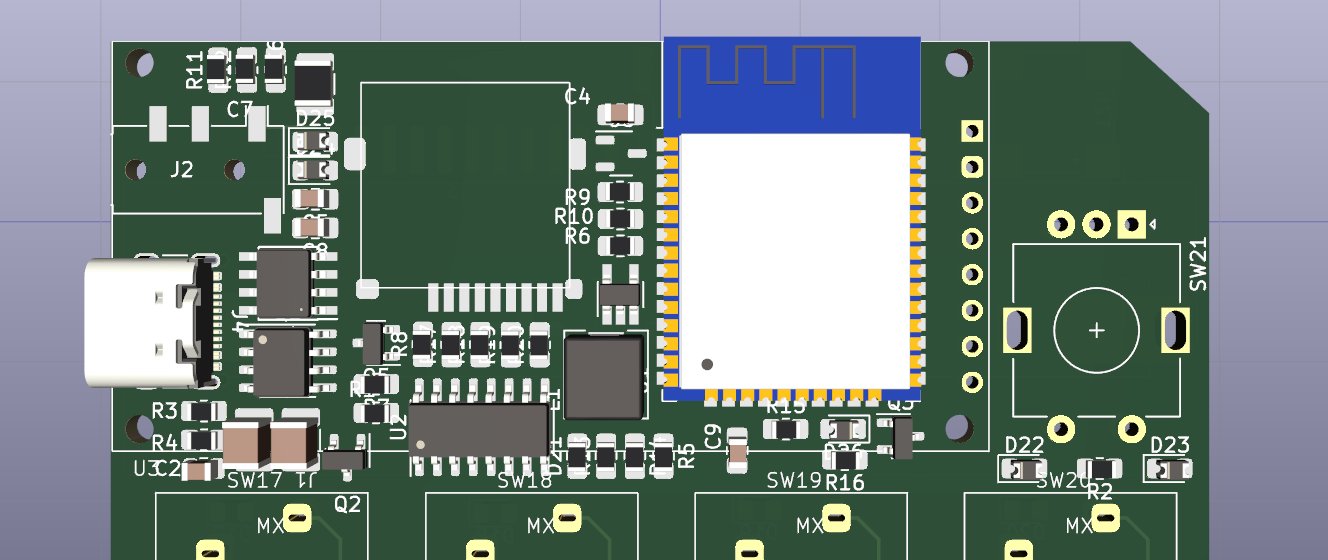
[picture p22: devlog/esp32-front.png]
ver 3 front

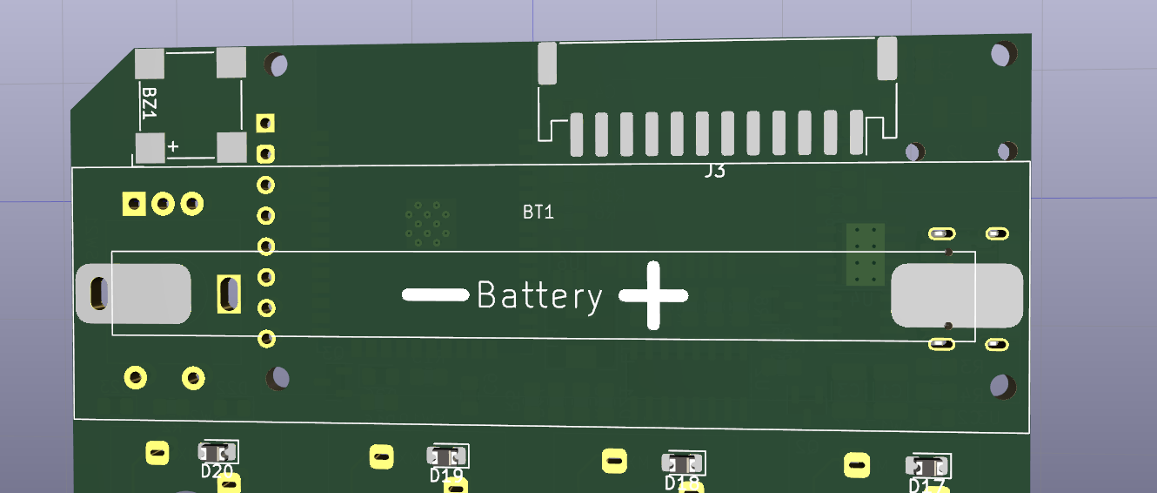
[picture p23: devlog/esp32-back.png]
ver 3 back


The battery connector was the biggest obstacle because the screen assembly is attached using hex standoffs, so either an odd number of standoffs was to be used, or the pcb had to be elongated, leaving the layout kind of ugly.

I also really wanted to add a headphone jack to test some audio programs, which left even less space.

### Version 4

This is the pivoting point as I had come back to this project so many times that looking at it made me want to throw it away each time I sat down to think about it.

The introduction of the ESP32 S3 improved almost everything about the chip and solved many of my layou problems and the previous version suffered from peripherals sharing many of the same pins which could not me changed, especially for the screen. 

With this version I was able to design the board like I wanted it to be from the beginning: no other thinking parts except the main core, meaning there was to be no other co processor on the board that would handle graphics, io etc. The ESP32 was to perform all these tasks. This was possible now because a lot of the S3 modules had build in PSRAM and the ULP could be coded in C, speeding up the debugging process significantly.

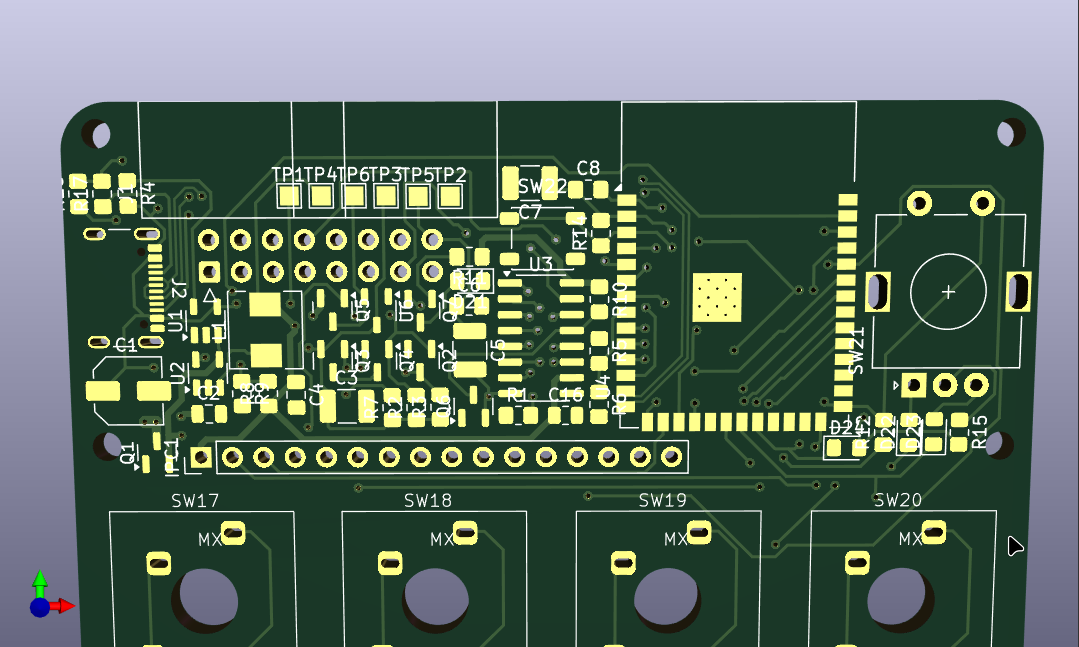
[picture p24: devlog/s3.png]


I also wanted the board to be two layers only to keep costs down. This proved to be a massive challenge in the layout process because I ran into thin ground traces multiple times and had to reroute my way to run the battery negative close to the regulator and other peripherals.

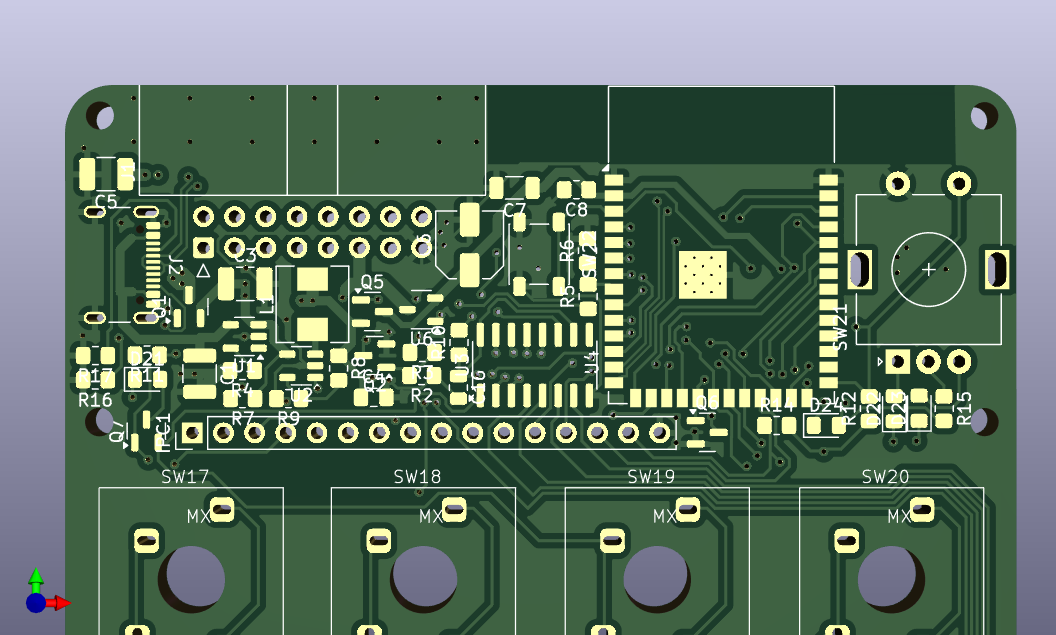
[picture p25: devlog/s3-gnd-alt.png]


This first few layout had some bugs that I had to bodge in post when I found out the hard way that I used the wrong footprint for the transistors that I *didn't* have :/
I also found out that my low power circuit powered down the board only to then come back up again, leaving the device on all the time unless the battery was out.



I experimented with pogo pins for the top screen assembly also but this turned out to be a not so great idea, both for debugging and for reliablilty, as the long line of pins bowed the board making the middle contacts not connect properly at times, or during shock when setting the board down on a table.

ver 4 pogo

ver 4 pogo screen

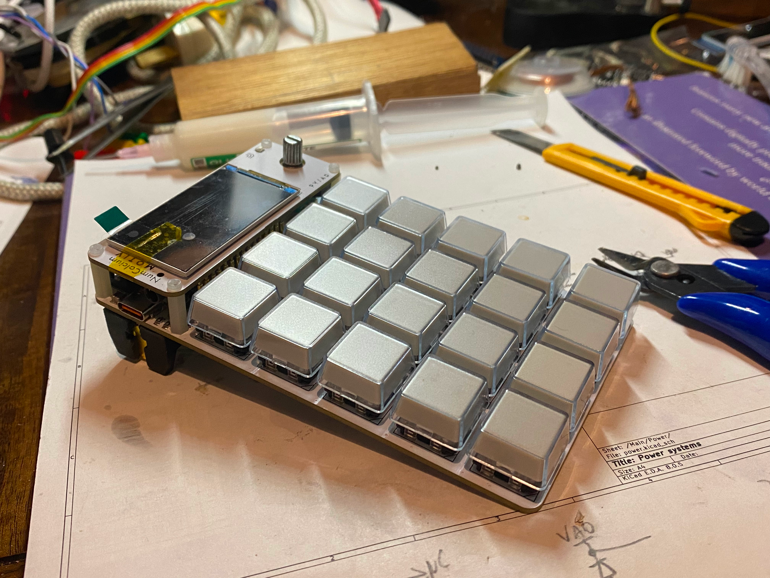
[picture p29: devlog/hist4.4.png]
var 4 build


At one point I wanted the device to be able to work like a full computer close to what you would use in the 80s, where a terminal would accept BASIC code.

It looks like its not possible to inject keystrokes into the `stdin` of MicroPython easily, so I was only stuck with the terminal output on the screen and no way to input characters without a host computer.

var 4 terminal


### Version 5

This is the current version which addressed almost all my concerns and issues in terms of hardware bug. 

The look is the same like in version 4 with the most notable change being the encoder design being streamlined to allow turing it from the side like a volume wheel.

It features a flat flex cable to connect the screen board to the main board, addressable LED under each key, and a buzzer and headphone jack which I wanted since version 1.

This is pretty much now the definite design as I cant see what could be improved, also there is little room left anyway and its tight enough to fix any cold solder joints by hand as it is.

final version

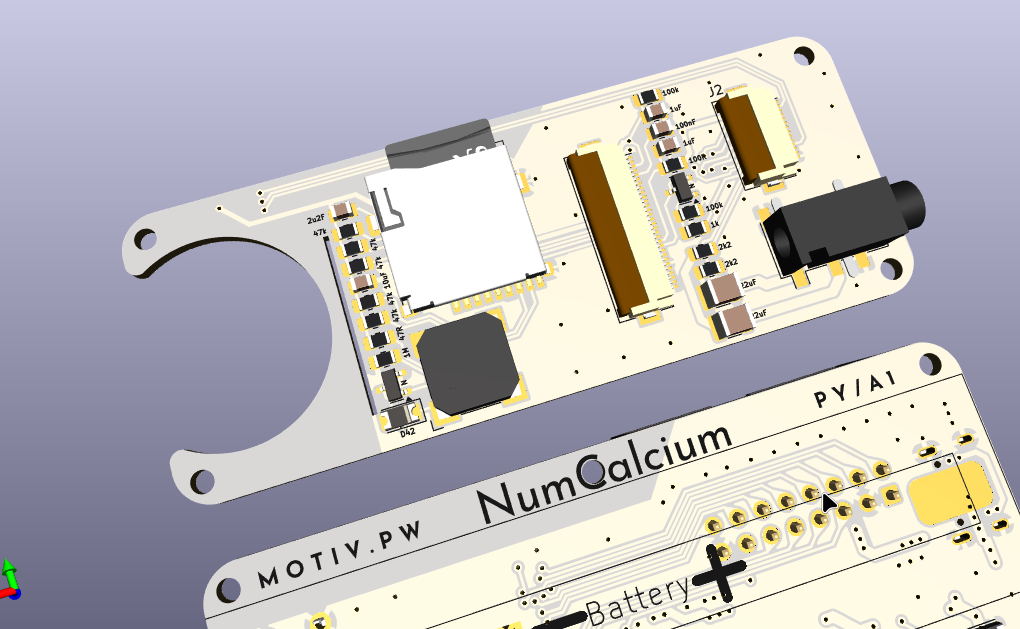
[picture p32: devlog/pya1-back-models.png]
final pcb front


The silkscreen is laid out to allow hand assembly without referencing a schematic, simply showing component values instead of designators.
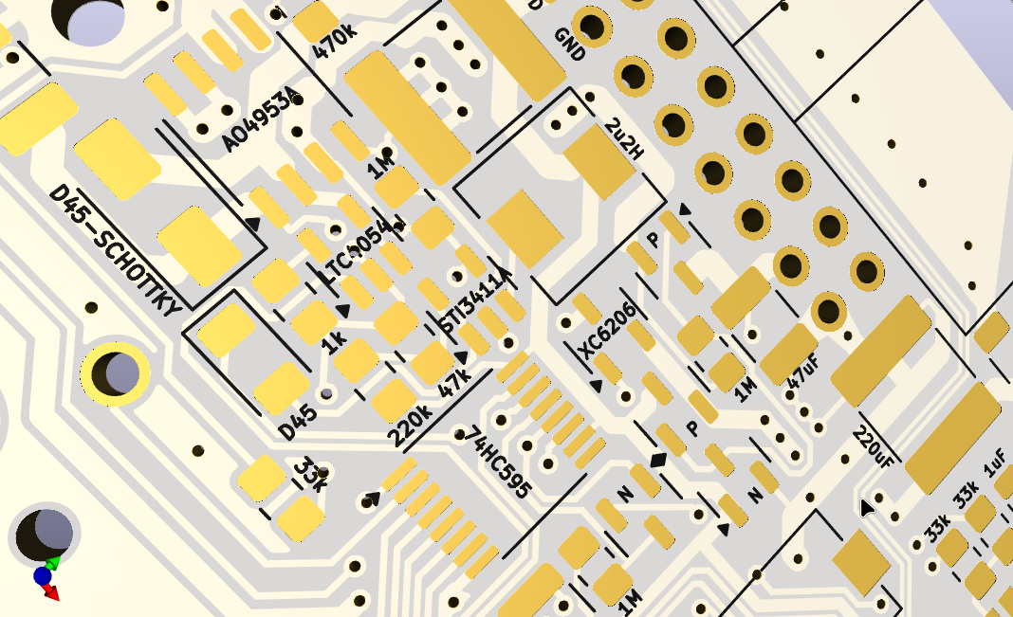
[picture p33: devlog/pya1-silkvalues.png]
final silkscreen


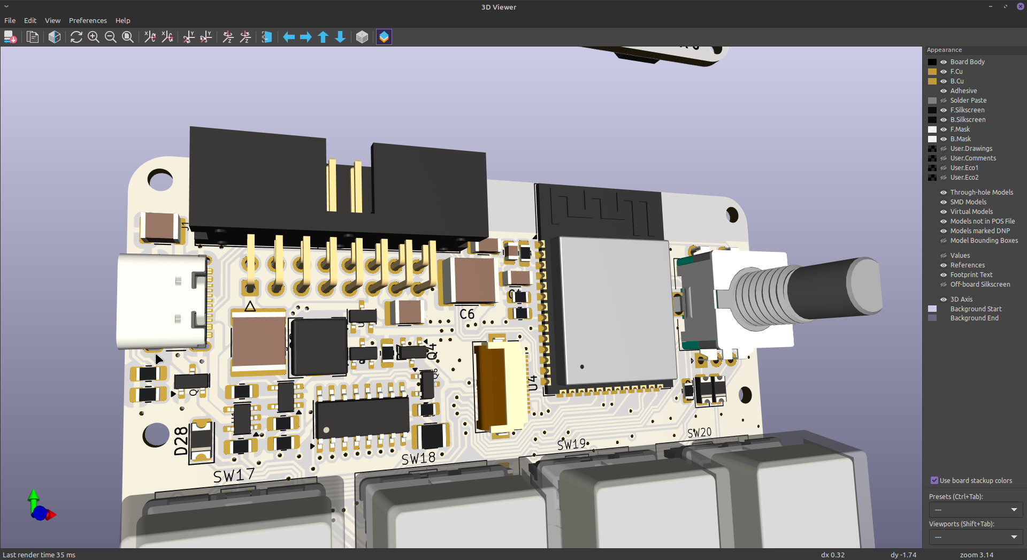
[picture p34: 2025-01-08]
devlog/pya0-main.png

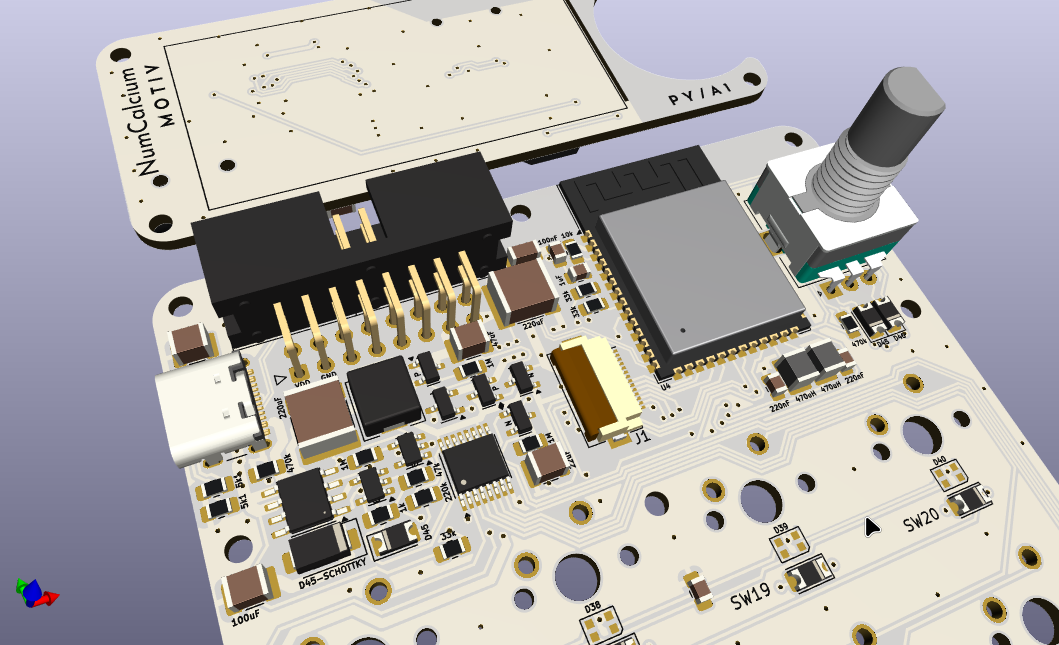
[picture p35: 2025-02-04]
devlog/pya1-front-models.png

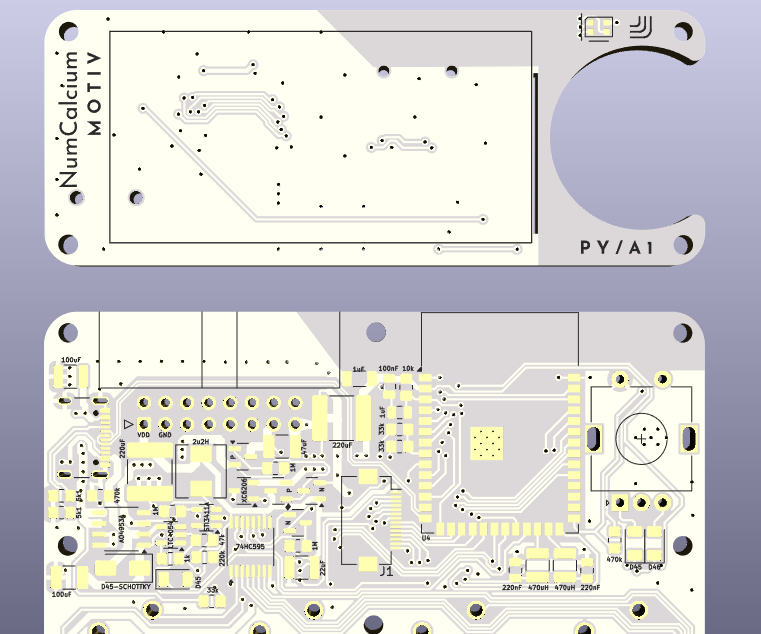
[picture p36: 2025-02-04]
devlog/pya1-all.png

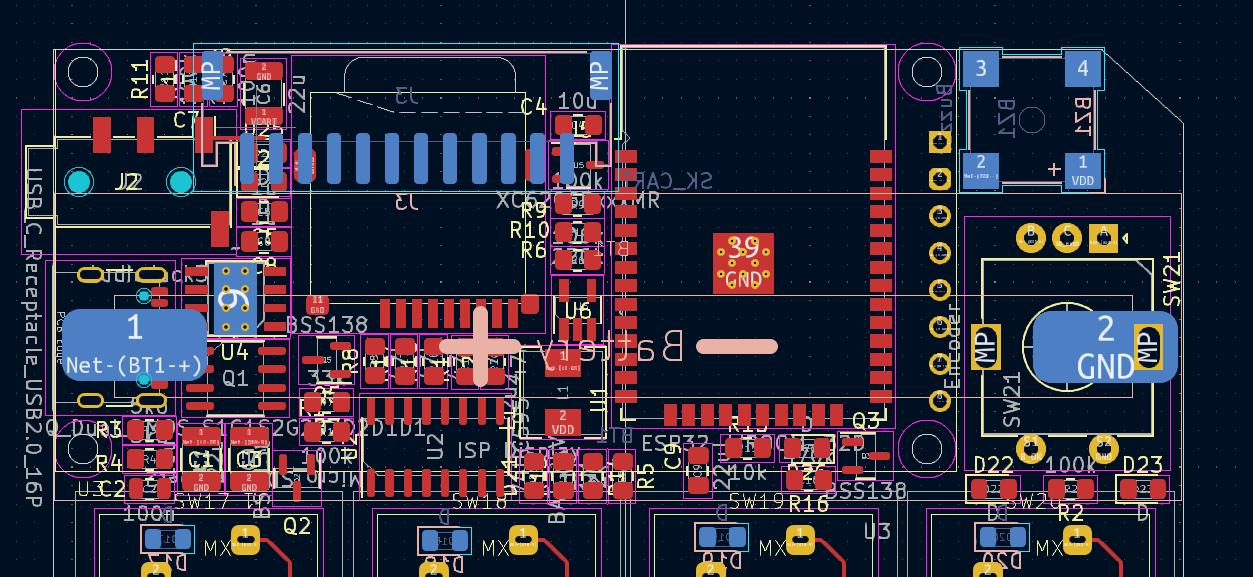
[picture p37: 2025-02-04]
devlog/esp32-cu.png

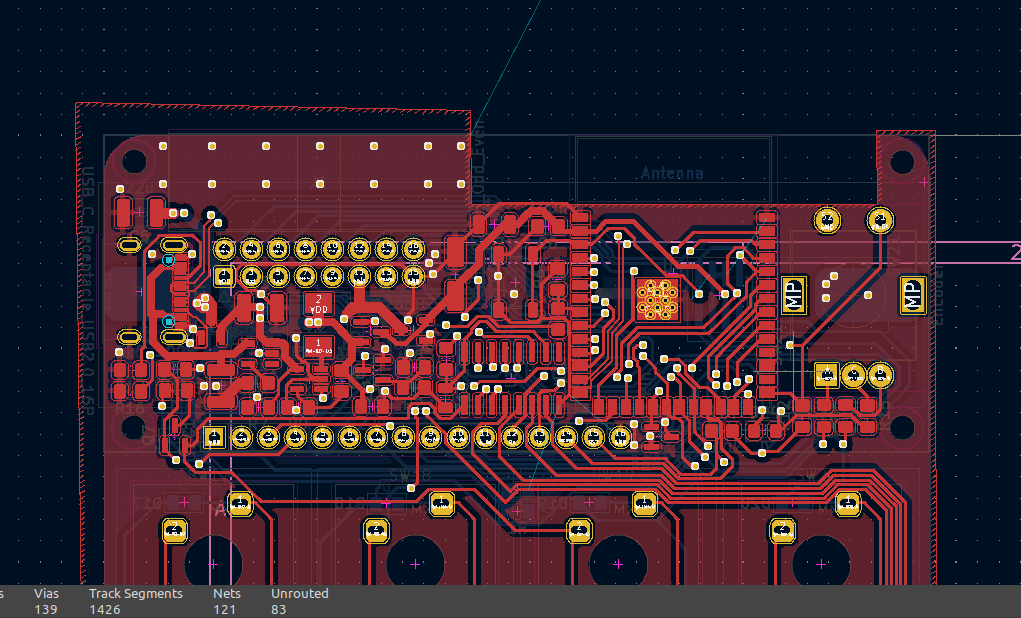
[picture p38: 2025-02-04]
devlog/s3-gnd-alt-fcu.png

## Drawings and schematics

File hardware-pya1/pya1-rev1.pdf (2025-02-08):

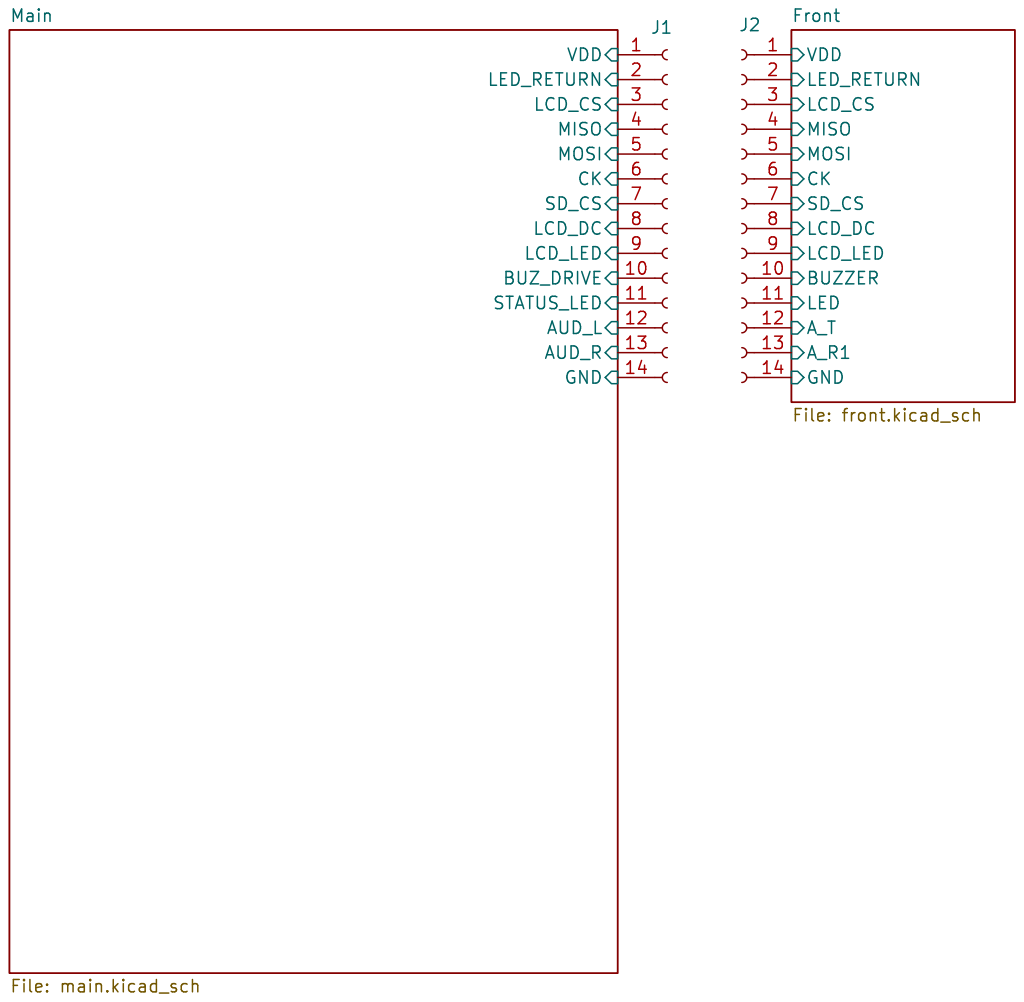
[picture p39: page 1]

File: numcalcium.kicad_sch Sheet: / MOTIV.PW

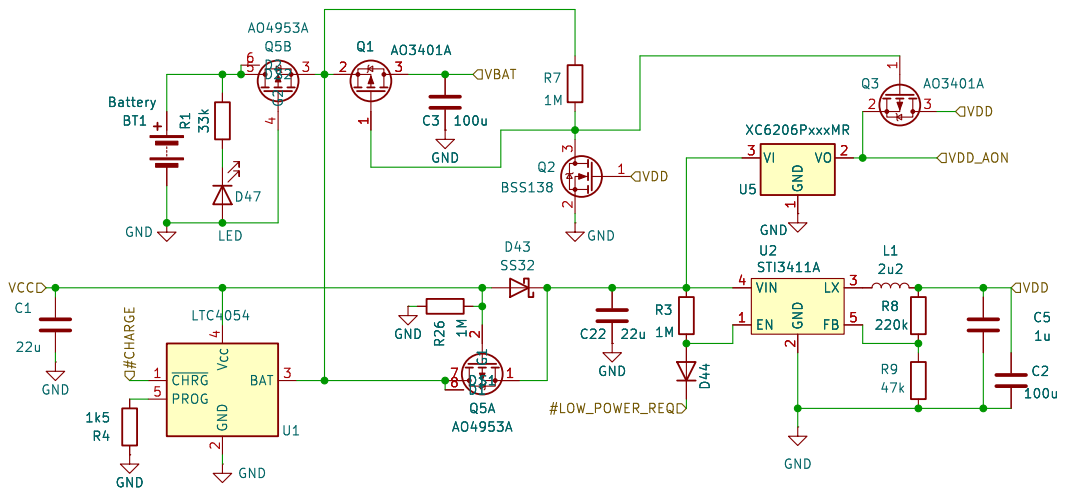
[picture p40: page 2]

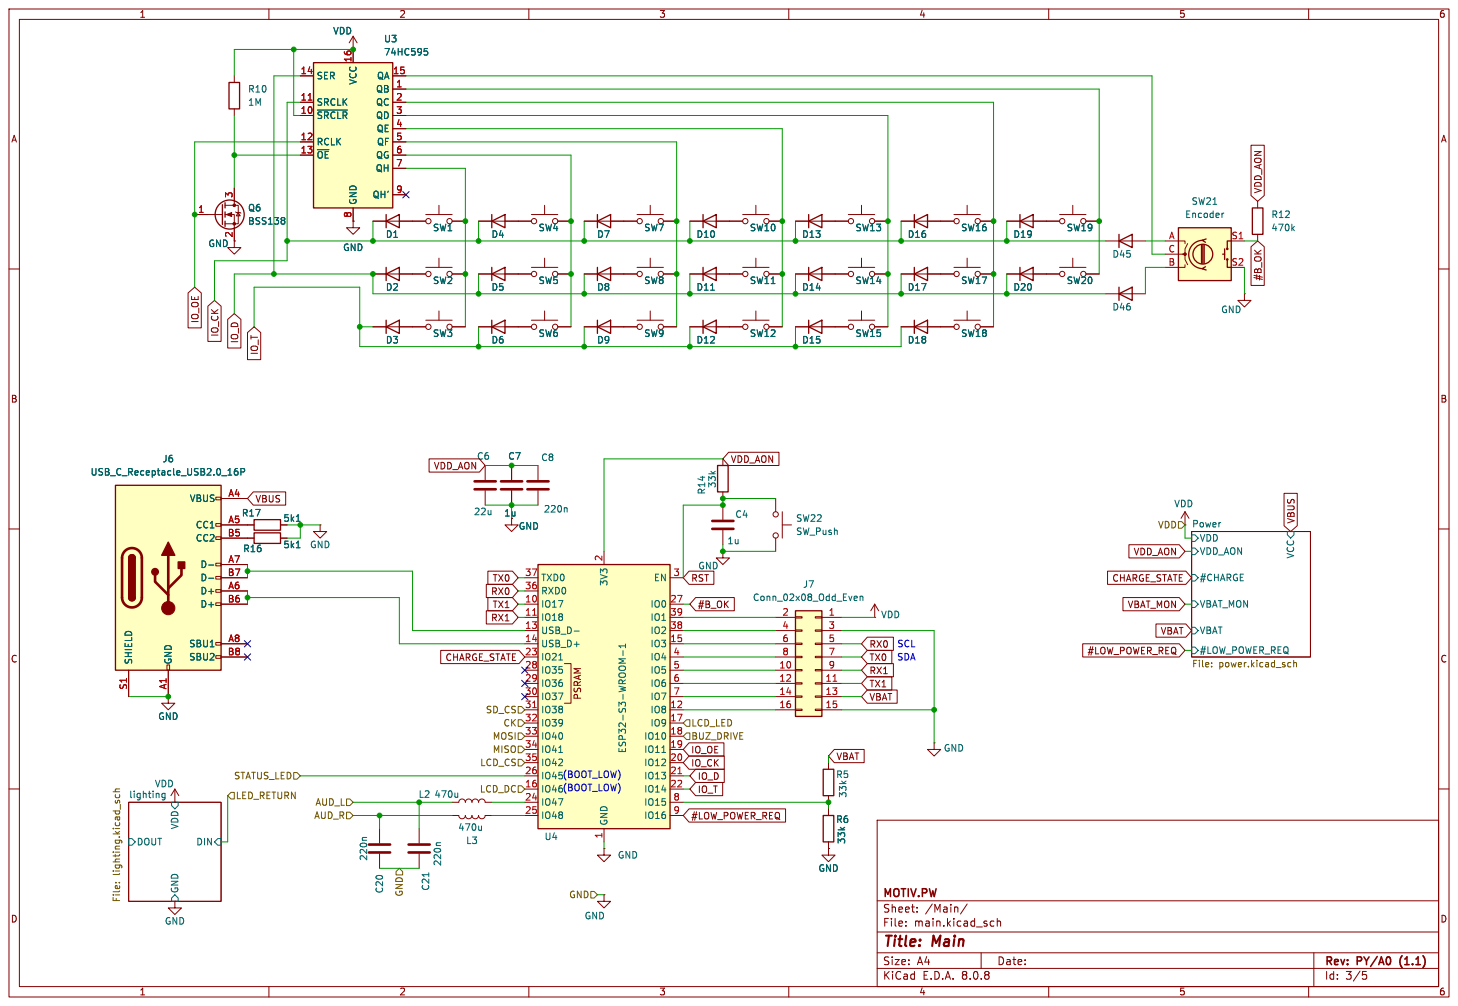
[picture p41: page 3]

File: main.kicad_sch Sheet: /Main/ MOTIV.PW GND VDD

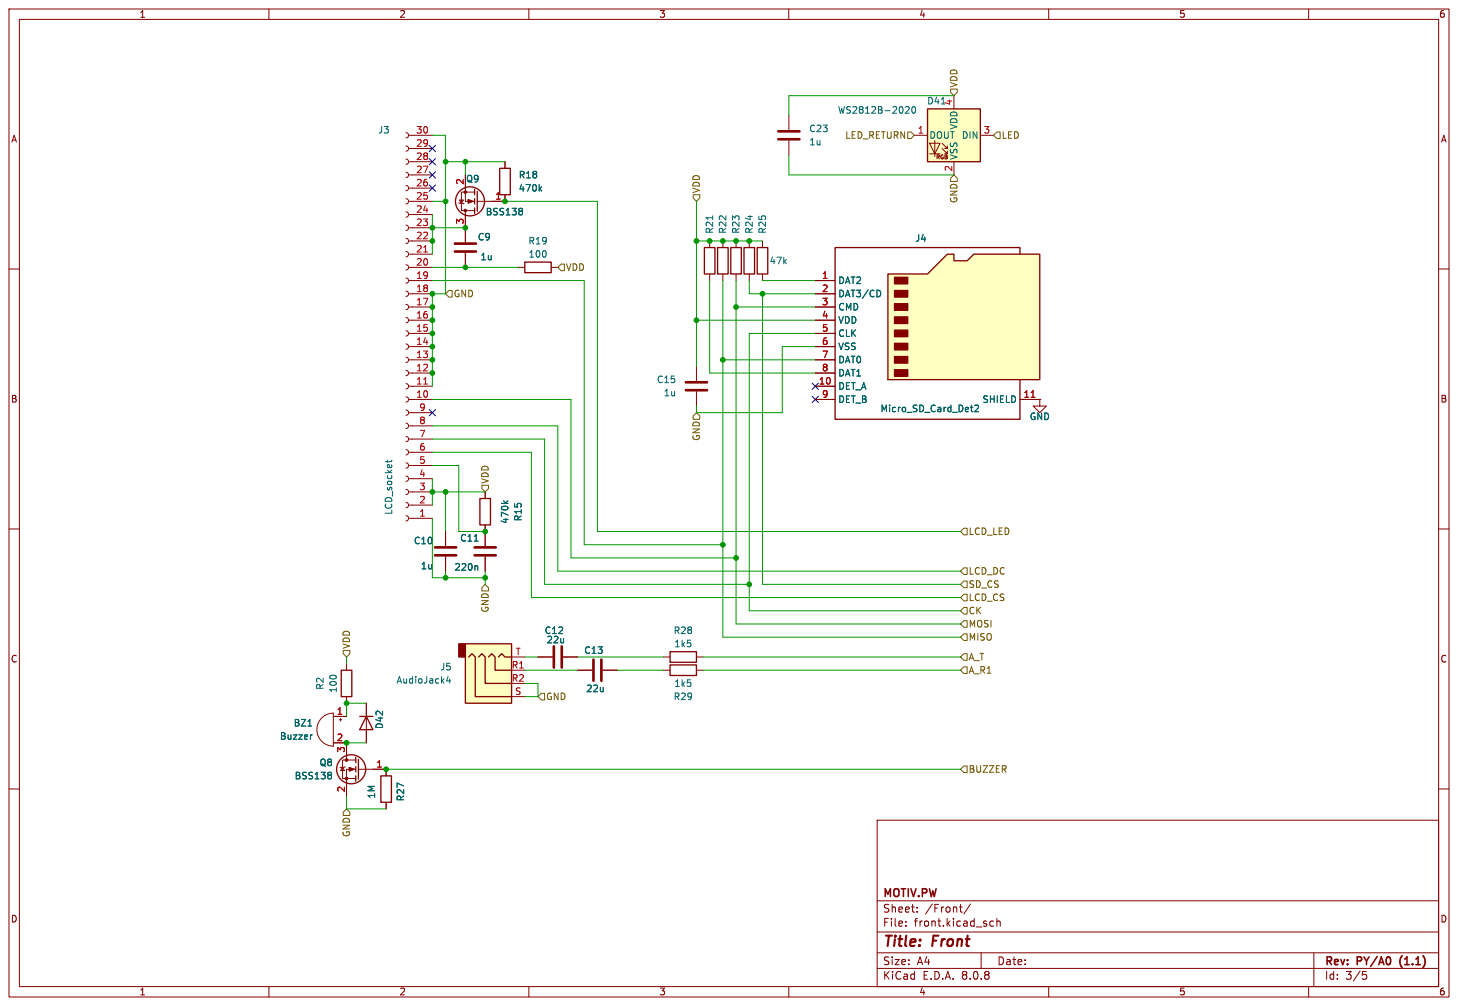
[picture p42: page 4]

Id: 3/5 Title: Front File: front.kicad_sch Sheet: /Front/ MOTIV.PW R27 1M

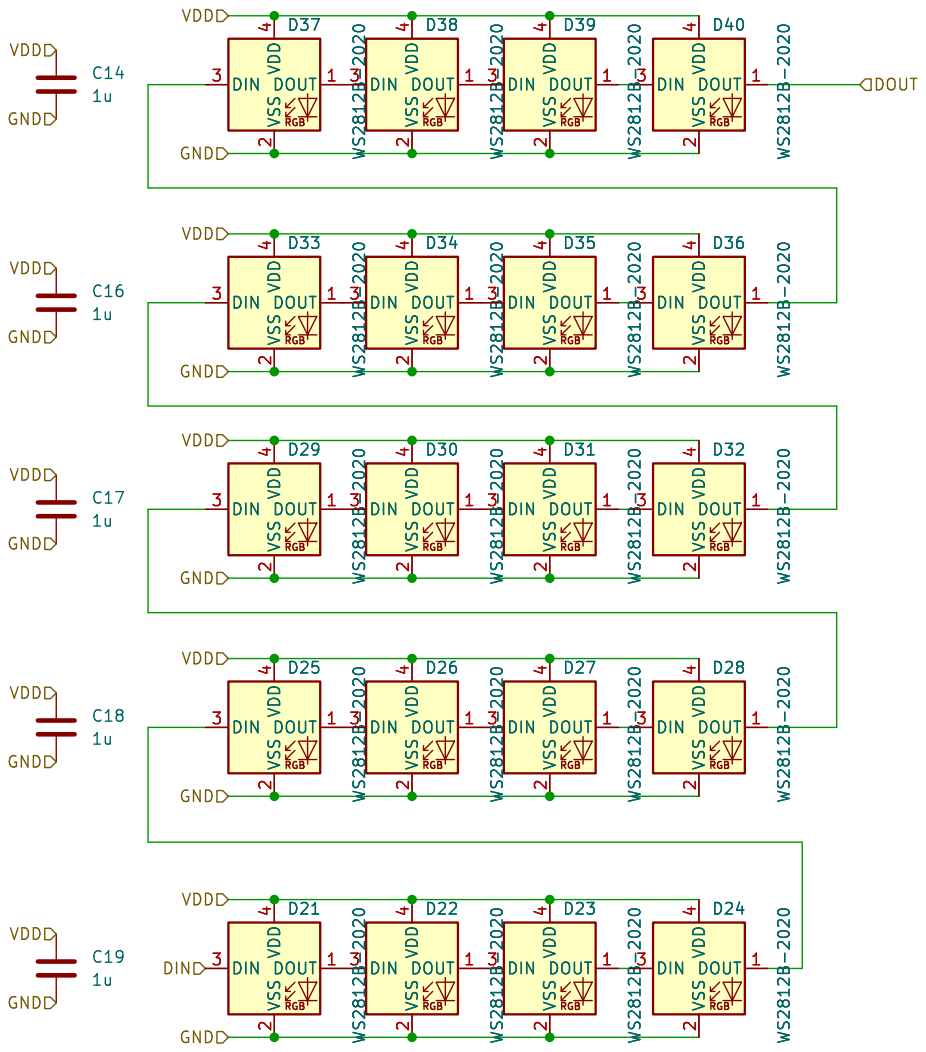
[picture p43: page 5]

File: lighting.kicad_sch Sheet: /Main/lighting/ MOTIV.PW

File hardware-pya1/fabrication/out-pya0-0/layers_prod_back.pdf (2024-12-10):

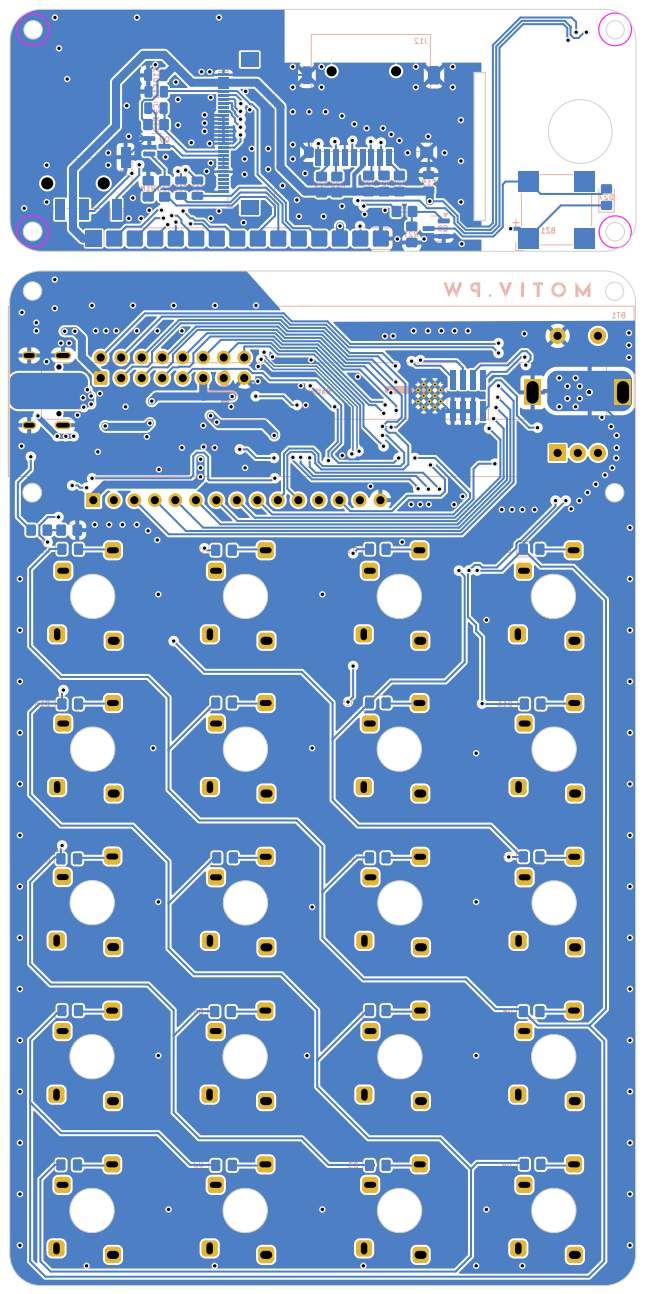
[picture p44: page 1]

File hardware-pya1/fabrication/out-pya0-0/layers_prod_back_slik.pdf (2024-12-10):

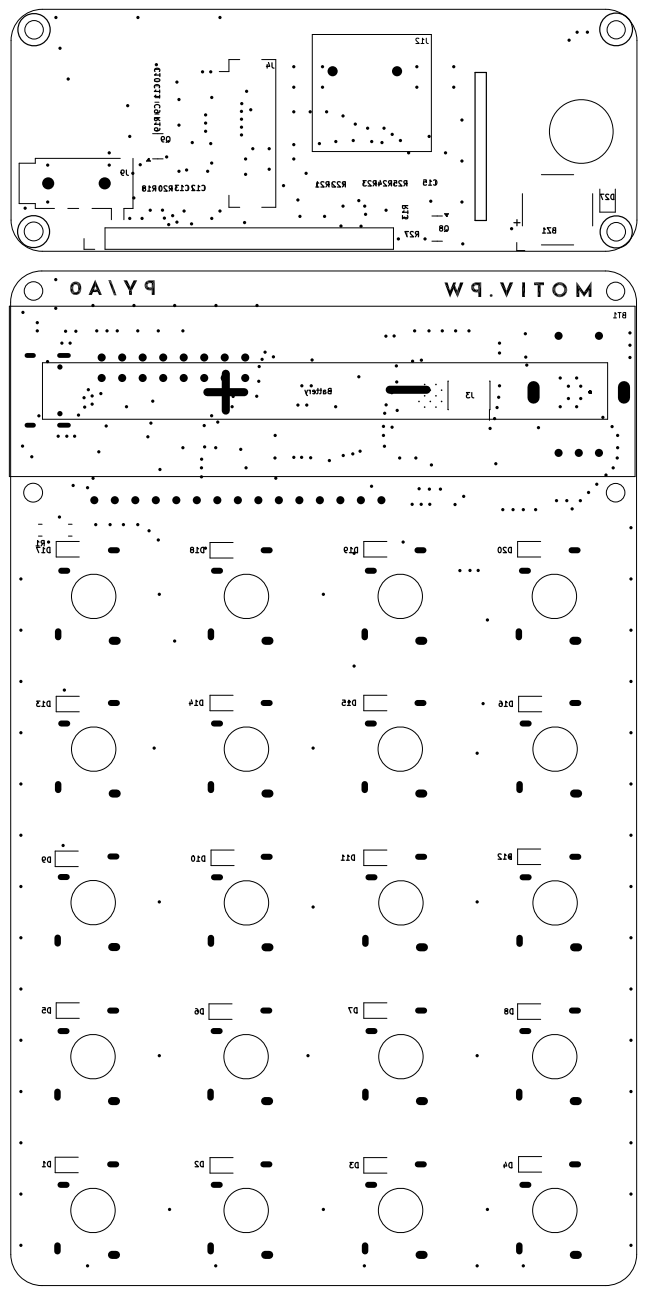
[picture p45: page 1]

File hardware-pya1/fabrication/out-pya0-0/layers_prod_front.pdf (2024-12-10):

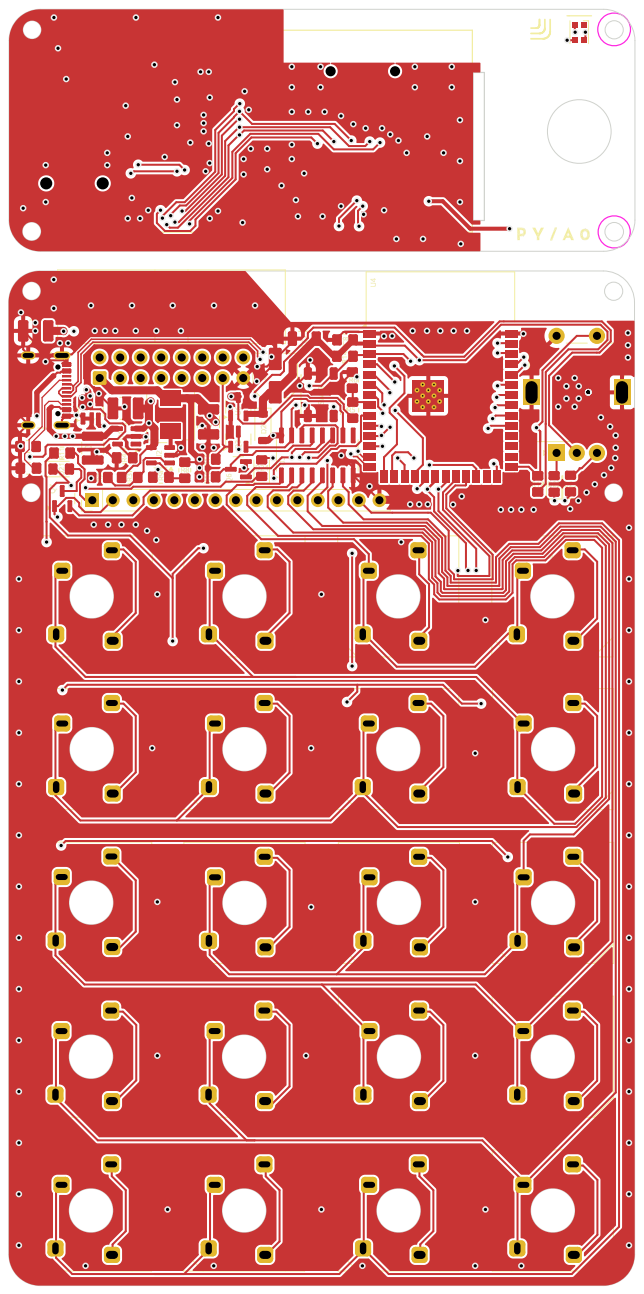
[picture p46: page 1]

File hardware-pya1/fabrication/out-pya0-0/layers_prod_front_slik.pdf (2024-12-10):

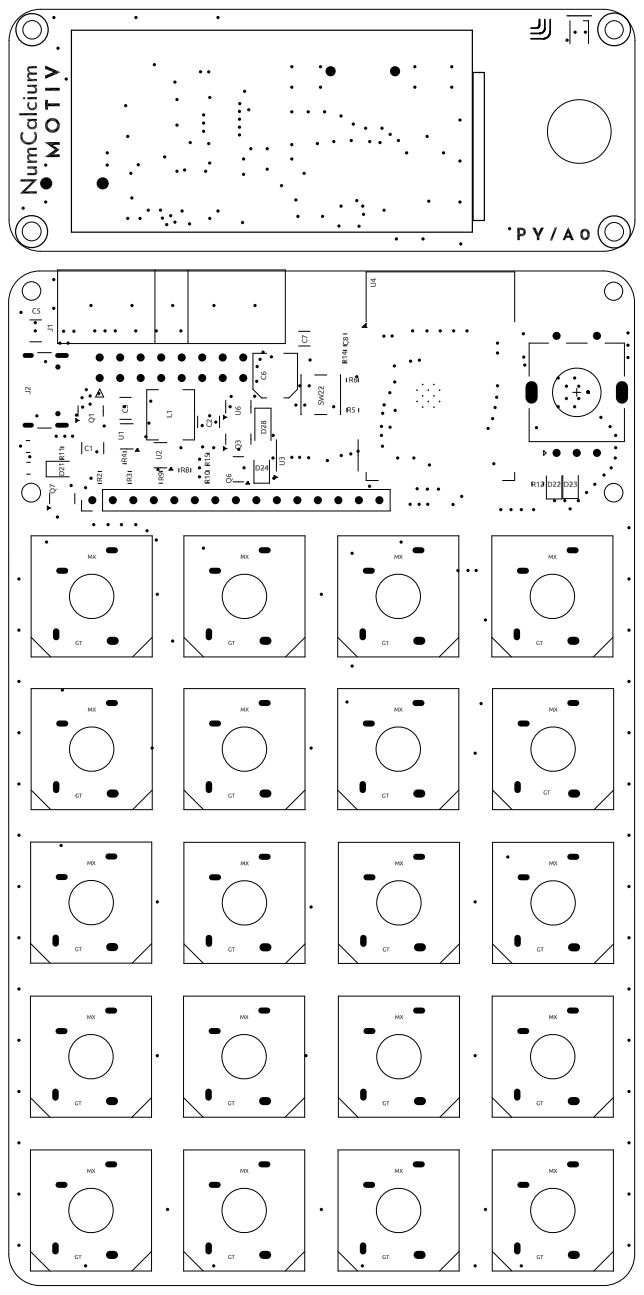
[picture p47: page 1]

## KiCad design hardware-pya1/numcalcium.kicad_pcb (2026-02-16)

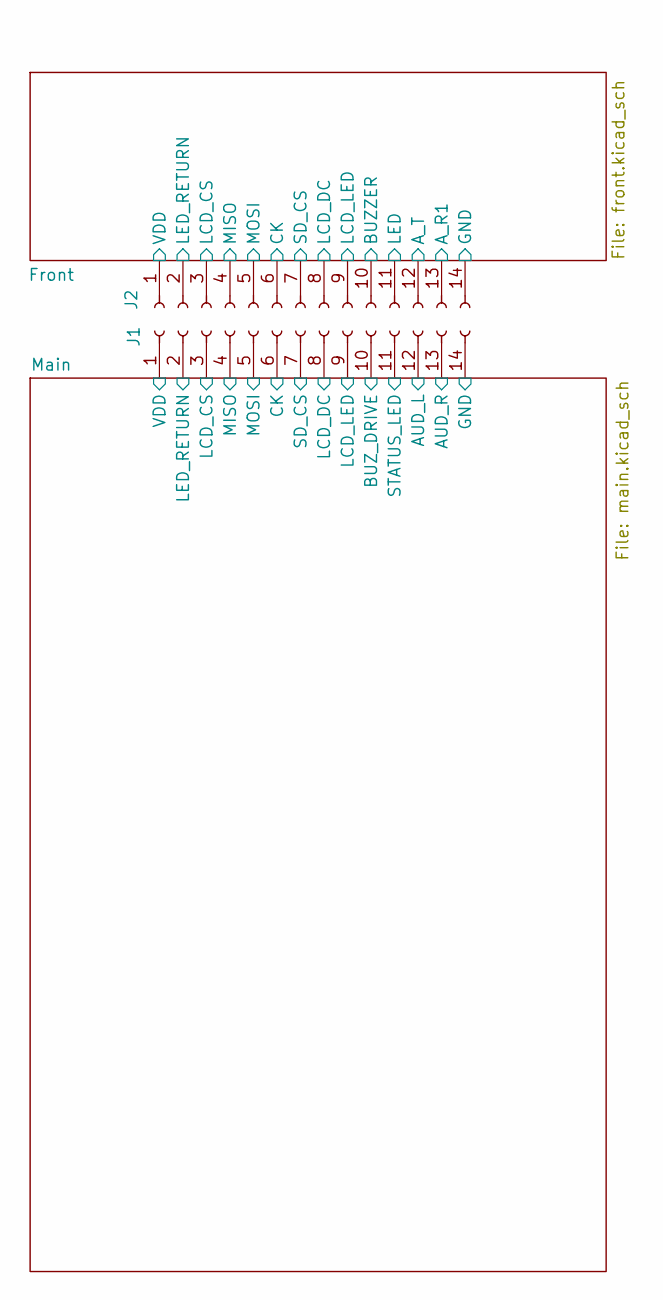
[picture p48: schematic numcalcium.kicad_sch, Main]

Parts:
J1, J2: Conn_01x14_Socket; Hirose_FH12-14S-0.5SH_1x14-1MP_P0.50mm_Horizontal

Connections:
/Front/A_R1: J2.13; also elsewhere on the board
/Front/A_T: J2.12; also elsewhere on the board
/Front/BUZZER: J2.10; also elsewhere on the board
/Front/CK: J2.6; also elsewhere on the board
/Front/GND: J2.14; also elsewhere on the board
/Front/LCD_CS: J2.3; also elsewhere on the board
/Front/LCD_DC: J2.8; also elsewhere on the board
/Front/LCD_LED: J2.9; also elsewhere on the board
/Front/LED: J2.11; also elsewhere on the board
/Front/LED_RETURN: J2.2; also elsewhere on the board
/Front/MISO: J2.4; also elsewhere on the board
/Front/MOSI: J2.5; also elsewhere on the board
/Front/SD_CS: J2.7; also elsewhere on the board
/Front/VDD: J2.1; also elsewhere on the board
/Main/AUD_L: J1.12; also elsewhere on the board
/Main/AUD_R: J1.13; also elsewhere on the board
/Main/BUZ_DRIVE: J1.10; also elsewhere on the board
/Main/CK: J1.6; also elsewhere on the board
/Main/LCD_CS: J1.3; also elsewhere on the board
/Main/LCD_DC: J1.8; also elsewhere on the board
/Main/LCD_LED: J1.9; also elsewhere on the board
/Main/LED_RETURN: J1.2; also elsewhere on the board
/Main/MISO: J1.4; also elsewhere on the board
/Main/MOSI: J1.5; also elsewhere on the board
/Main/SD_CS: J1.7; also elsewhere on the board
/Main/STATUS_LED: J1.11; also elsewhere on the board
GND: J1.14; also elsewhere on the board
VDD: J1.1; also elsewhere on the board

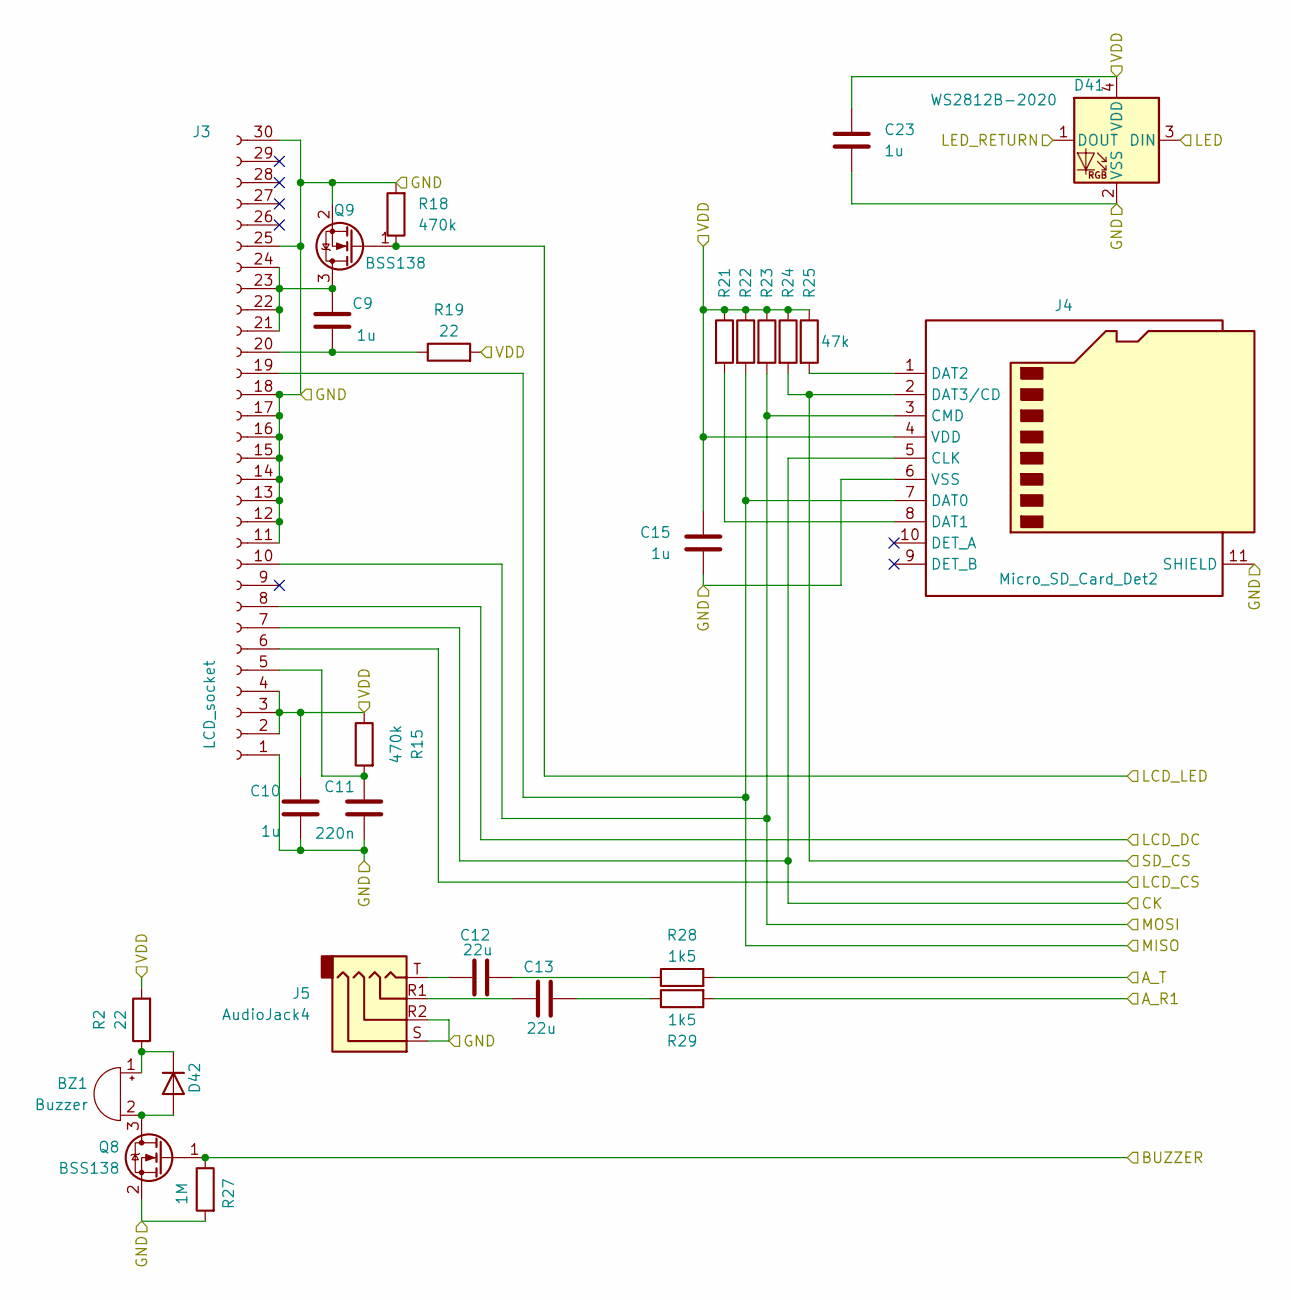
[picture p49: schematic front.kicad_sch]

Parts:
BZ1: Buzzer; MagneticBuzzer_CUI_CMT-8504-100-SMT
C9, C10, C15, C23: 1u; C_0805_2012Metric_Pad1.18x1.45mm_HandSolder
C11: 220n; C_0805_2012Metric_Pad1.18x1.45mm_HandSolder
C12, C13: 22u; C_1206_3216Metric_Pad1.33x1.80mm_HandSolder
D41: WS2812B-2020; LED_WS2812B-2020_PLCC4_2.0x2.0mm
D42: 1N4148; D_1206_3216Metric
J3: LCD_socket; Hirose_FH12-30S-0.5SH_1x30-1MP_P0.50mm_Horizontal
J4: Micro_SD_Card_Det2; microSD_Short_1
J5: AudioJack4; Jack_3.5mm_PJ320D_Horizontal
Q8, Q9: BSS138; SOT-23
R2, R19: 22; R_0805_2012Metric_Pad1.20x1.40mm_HandSolder
R15, R18: 470k; R_0805_2012Metric_Pad1.20x1.40mm_HandSolder
R21, R22, R23, R24, R25: 47k; R_0805_2012Metric_Pad1.20x1.40mm_HandSolder
R27: 1M; R_0805_2012Metric_Pad1.20x1.40mm_HandSolder
R28, R29: 1k5; R_0805_2012Metric_Pad1.20x1.40mm_HandSolder

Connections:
/Front/A_R1: R29.2; also elsewhere on the board
/Front/A_T: R28.2; also elsewhere on the board
/Front/BUZZER: Q8.1 (G), R27.1; also elsewhere on the board
/Front/CK: J3.7, J4.5 (CLK); also elsewhere on the board
/Front/GND: C10.2, C11.2, C15.2, C23.2, D41.2 (VSS), J3.1, J3.11, J3.12, J3.13, J3.14, J3.15, J3.16, J3.17, J3.18, J3.25, J3.30, J4.6 (VSS), J4.11 (SHIELD), J5.R2, J5.S, Q8.2 (S), Q9.2 (S), R18.2, R27.2; also elsewhere on the board
/Front/LCD_CS: J3.6; also elsewhere on the board
/Front/LCD_DC: J3.8; also elsewhere on the board
/Front/LCD_LED: Q9.1 (G), R18.1; also elsewhere on the board
/Front/LED: D41.3 (DIN); also elsewhere on the board
/Front/LED_RETURN: D41.1 (DOUT); also elsewhere on the board
/Front/MISO: J3.19, J4.7 (DAT0), R22.2; also elsewhere on the board
/Front/MOSI: J3.10, J4.3 (CMD), R23.2; also elsewhere on the board
/Front/SD_CS: J4.2 (DAT3/CD), R24.2; also elsewhere on the board
/Front/VDD: C10.1, C15.1, C23.1, D41.4 (VDD), J3.2, J3.3, J3.4, J4.4 (VDD), R2.2, R15.1, R19.2, R21.1, R22.1, R23.1, R24.1, R25.1; also elsewhere on the board
unnamed: BZ1.1 (+), D42.1 (K), R2.1
unnamed: BZ1.2 (-), D42.2 (A), Q8.3 (D)
unnamed: C12.1, J5.T
unnamed: C12.2, R28.1
unnamed: C13.1, J5.R1
unnamed: C13.2, R29.1
unnamed: C11.1, J3.5, R15.2
unnamed: C9.2, J3.20, R19.1
unnamed: C9.1, J3.21, J3.22, J3.23, J3.24, Q9.3 (D)
unnamed: J4.8 (DAT1), R21.2
unnamed: J4.1 (DAT2), R25.2

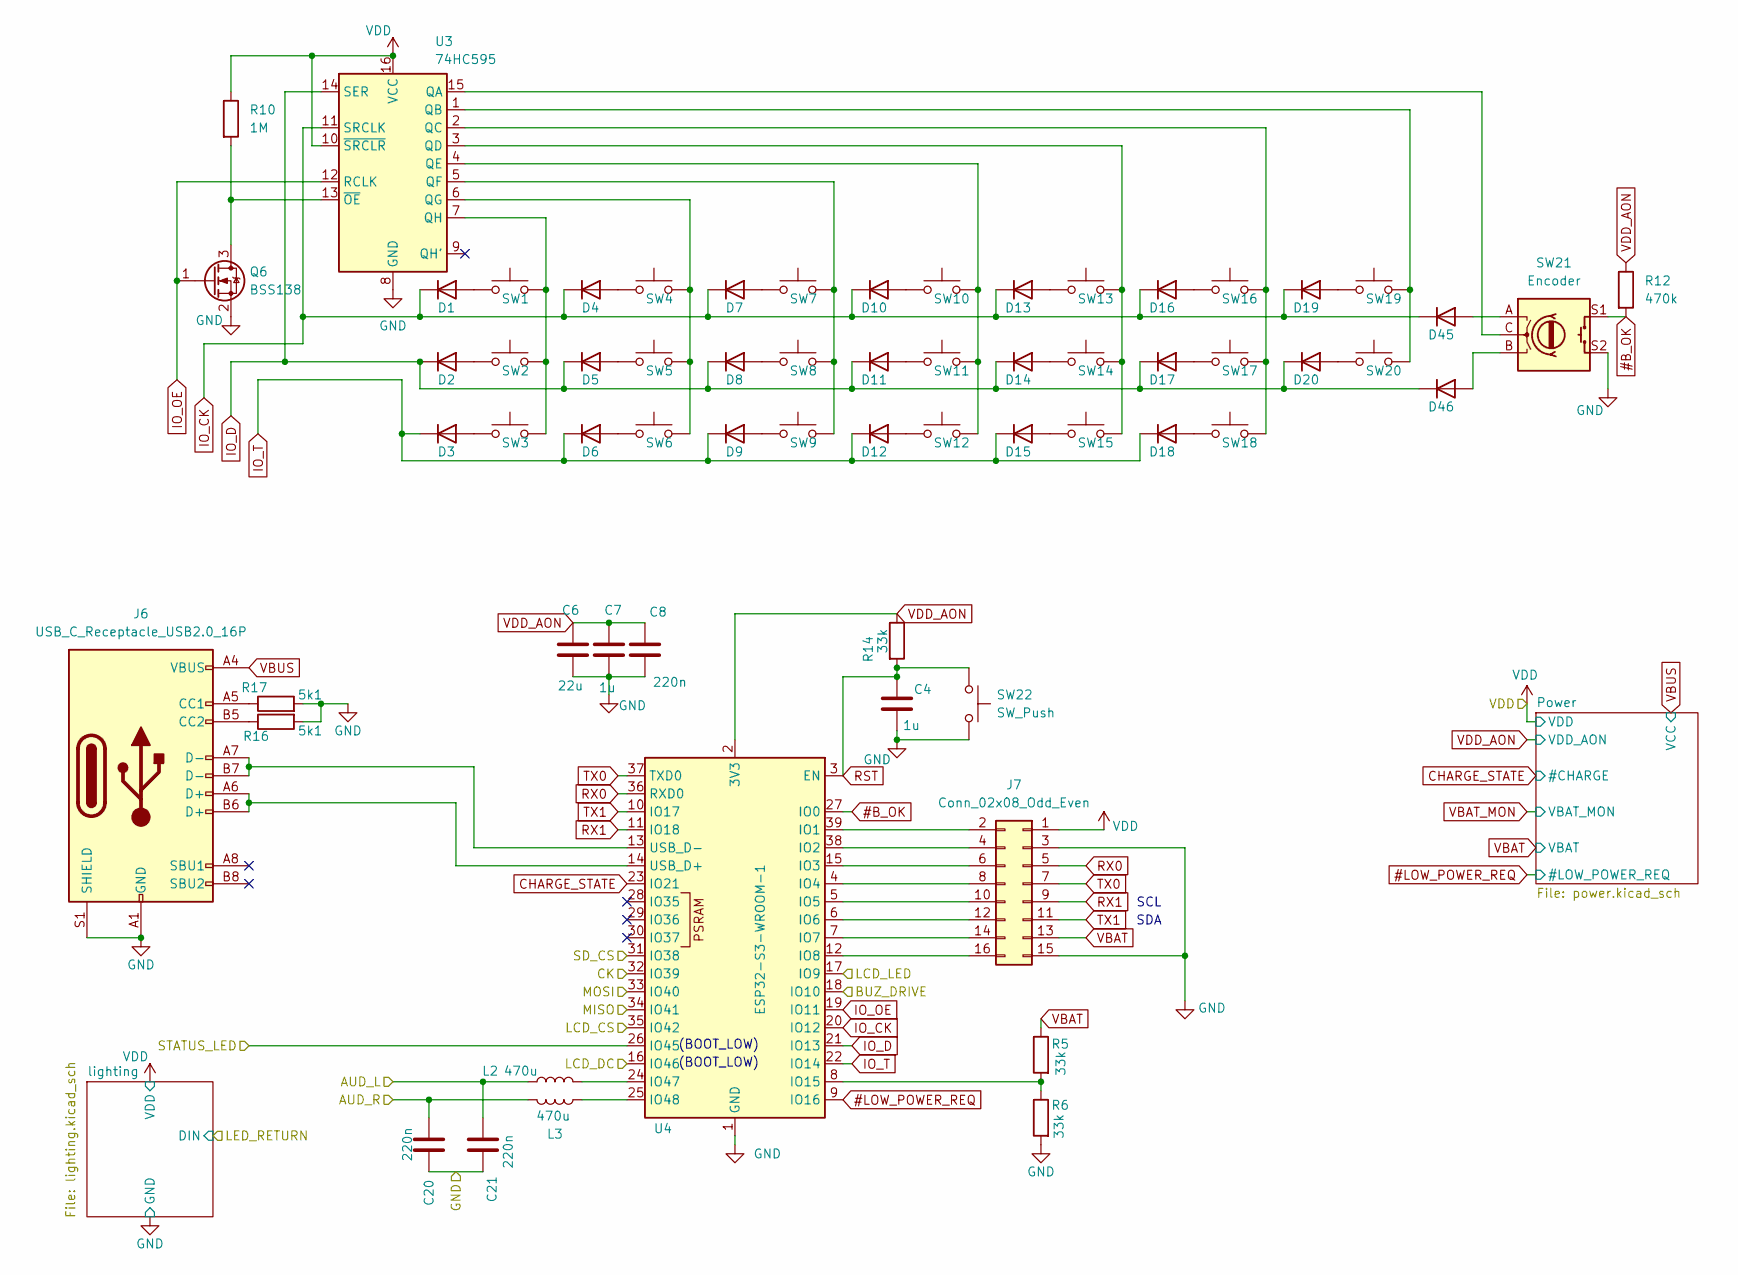
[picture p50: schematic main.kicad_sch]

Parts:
C4, C7: 1u; C_0805_2012Metric_Pad1.18x1.45mm_HandSolder
C6: 22u; C_1206_3216Metric_Pad1.33x1.80mm_HandSolder
C8, C20, C21: 220n; C_0805_2012Metric_Pad1.18x1.45mm_HandSolder
D1, D2, D3, D4, D5, D6, D7, D8, D9, D10, D11, D12, D13, D14, D15, D16, D17, D18, D19, D20, D45, D46: 1N4148; D_1206_3216Metric
J6: USB_C_Receptacle_USB2.0_16P; USB_C_Receptacle_GCT_USB4105-xx-A_16P_TopMnt_Horizontal
J7: Conn_02x08_Odd_Even; IDC-Header_2x08_P2.54mm_Horizontal
L2, L3: 470u; L_1210_3225Metric
Q6: BSS138; SOT-23
R5, R6, R14: 33k; R_0805_2012Metric_Pad1.20x1.40mm_HandSolder
R10: 1M; R_0805_2012Metric_Pad1.20x1.40mm_HandSolder
R12: 470k; R_0805_2012Metric_Pad1.20x1.40mm_HandSolder
R16, R17: 5k1; R_0805_2012Metric_Pad1.20x1.40mm_HandSolder
SW1, SW2, SW3, SW4, SW5, SW6, SW7, SW8, SW9, SW10, SW11, SW12, SW13, SW14, SW15, SW16, SW17, SW18, SW19, SW20: SW_Push; SW_Cherry_MX_1.00u_PCB
SW21: Encoder; RotaryEncoder_Alps_EC11E-Switch_Vertical_H20mm
SW22: SW_Push; SW_SPST_PTS647_Sx38
U3: 74HC595; TSSOP-16_4.4x5mm_P0.65mm
U4: ESP32-S3-WROOM-1; ESP32-S3-WROOM-1-Compact-Court

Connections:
#B_OK: R12.2, SW21.S1, U4.27 (IO0)
#LOW_POWER_REQ: U4.9 (IO16); also elsewhere on the board
/Main/AUD_L: C21.2, L2.1; also elsewhere on the board
/Main/AUD_R: C20.2, L3.2; also elsewhere on the board
/Main/BUZ_DRIVE: U4.18 (IO10); also elsewhere on the board
/Main/CK: U4.32 (IO39); also elsewhere on the board
/Main/LCD_CS: U4.35 (IO42); also elsewhere on the board
/Main/LCD_DC: U4.16 (IO46); also elsewhere on the board
/Main/LCD_LED: U4.17 (IO9); also elsewhere on the board
/Main/MISO: U4.34 (IO41); also elsewhere on the board
/Main/MOSI: U4.33 (IO40); also elsewhere on the board
/Main/SD_CS: U4.31 (IO38); also elsewhere on the board
/Main/STATUS_LED: U4.26 (IO45); also elsewhere on the board
CHARGE_STATE: U4.23 (IO21); also elsewhere on the board
GND: C4.2, C6.2, C7.2, C8.2, C20.1, C21.1, J6.A1 (GND), J6.A12 (GND), J6.B1 (GND), J6.B12 (GND), J6.S1 (SHIELD), J7.3, J7.15, Q6.2 (S), R6.2, R16.2, R17.2, SW21.S2, SW22.2, U3.8 (GND), U4.1 (GND), U4.40 (GND), U4.41 (GND); also elsewhere on the board
IO_CK: D1.1 (K), D4.1 (K), D7.1 (K), D10.1 (K), D13.1 (K), D16.1 (K), D19.1 (K), D45.1 (K), U3.11 (SRCLK), U4.20 (IO12)
IO_D: D2.1 (K), D5.1 (K), D8.1 (K), D11.1 (K), D14.1 (K), D17.1 (K), D20.1 (K), D46.1 (K), U3.14 (SER), U4.21 (IO13)
IO_OE: Q6.1 (G), U3.12 (RCLK), U4.19 (IO11)
IO_T: D3.1 (K), D6.1 (K), D9.1 (K), D12.1 (K), D15.1 (K), D18.1 (K), U4.22 (IO14)
unnamed: D1.2 (A), SW1.2
unnamed: D2.2 (A), SW2.2
unnamed: D3.2 (A), SW3.2
unnamed: D4.2 (A), SW4.2
unnamed: D5.2 (A), SW5.2
unnamed: D6.2 (A), SW6.2
unnamed: D7.2 (A), SW7.2
unnamed: D8.2 (A), SW8.2
unnamed: D9.2 (A), SW9.2
unnamed: D10.2 (A), SW10.2
unnamed: D11.2 (A), SW11.2
unnamed: D12.2 (A), SW12.2
unnamed: D13.2 (A), SW13.2
unnamed: D14.2 (A), SW14.2
unnamed: D15.2 (A), SW15.2
unnamed: D16.2 (A), SW16.2
unnamed: D17.2 (A), SW17.2
unnamed: D18.2 (A), SW18.2
unnamed: D19.2 (A), SW19.2
unnamed: D20.2 (A), SW20.2
unnamed: D45.2 (A), SW21.A
unnamed: D46.2 (A), SW21.B
unnamed: J6.A5 (CC1), R17.1
unnamed: J6.B5 (CC2), R16.1
unnamed: J7.2, U4.39 (IO1)
unnamed: J7.4, U4.38 (IO2)
unnamed: J7.6, U4.15 (IO3)
unnamed: J7.8, U4.4 (IO4)
unnamed: J7.10, U4.5 (IO5)
unnamed: J7.12, U4.6 (IO6)
unnamed: J7.14, U4.7 (IO7)
unnamed: J7.16, U4.12 (IO8)
unnamed: Q6.3 (D), R10.2, U3.13 (~OE)
unnamed: SW21.C, U3.15 (QA)
unnamed: SW19.1, SW20.1, U3.1 (QB)
unnamed: SW16.1, SW17.1, SW18.1, U3.2 (QC)
unnamed: SW13.1, SW14.1, SW15.1, U3.3 (QD)
unnamed: SW10.1, SW11.1, SW12.1, U3.4 (QE)
unnamed: SW7.1, SW8.1, SW9.1, U3.5 (QF)
unnamed: SW4.1, SW5.1, SW6.1, U3.6 (QG)
unnamed: SW1.1, SW2.1, SW3.1, U3.7 (QH)
unnamed: R5.2, R6.1, U4.8 (IO15)
unnamed: L2.2, U4.24 (IO47)
unnamed: L3.1, U4.25 (IO48)
unnamed: J6.A6 (D+), J6.B6 (D+), U4.14 (USB_D+)
unnamed: J6.A7 (D-), J6.B7 (D-), U4.13 (USB_D-)
RST: C4.1, R14.2, SW22.1, U4.3 (EN)
RX0: J7.5, U4.36 (RXD0)
RX1: J7.9, U4.11 (IO18)
TX0: J7.7, U4.37 (TXD0)
TX1: J7.11, U4.10 (IO17)
VBAT: J7.13, R5.1; also elsewhere on the board
VBUS: J6.A4 (VBUS), J6.A9 (VBUS), J6.B4 (VBUS), J6.B9 (VBUS); also elsewhere on the board
VDD: J7.1, R10.1, U3.10 (~SRCLR), U3.16 (VCC); also elsewhere on the board
VDD_AON: C6.1, C7.1, C8.1, R12.1, R14.1, U4.2 (3V3); also elsewhere on the board

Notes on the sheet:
SCL
(BOOT_LOW)
SDA

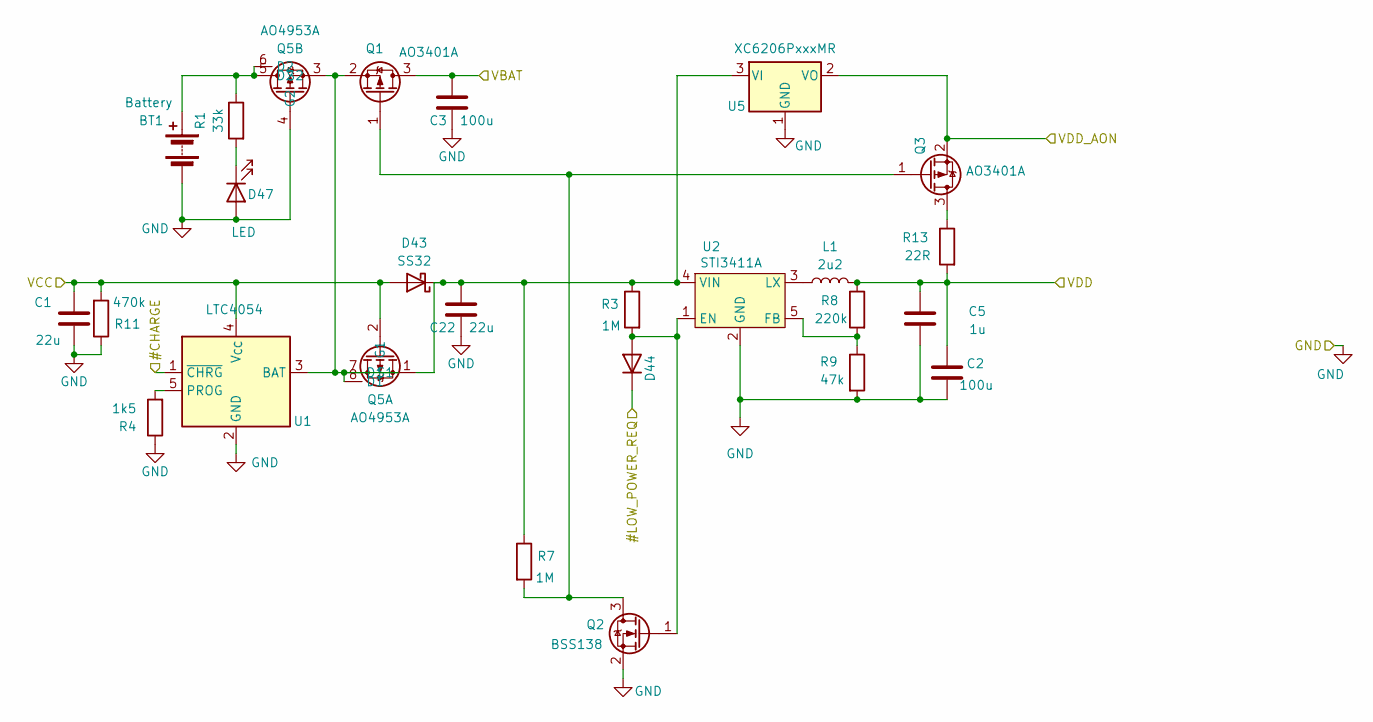
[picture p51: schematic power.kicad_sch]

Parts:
BT1: Battery; LiIon18650
C1, C22: 22u; C_1206_3216Metric_Pad1.33x1.80mm_HandSolder
C2, C3: 100u; CP_EIA-7343-31_Kemet-D
C5: 1u; C_0805_2012Metric_Pad1.18x1.45mm_HandSolder
D43: SS32; D_SMA
D44: 1N4148; D_1206_3216Metric
D47: LED; D_1206_3216Metric
L1: 2u2; L_Chilisin_BMRA00050530
Q1, Q3: AO3401A; SOT-23
Q2: BSS138; SOT-23
Q5: AO4953A; SOP-8_3.9x4.9mm_P1.27mm
R1: 33k; R_0805_2012Metric_Pad1.20x1.40mm_HandSolder
R3, R7: 1M; R_0805_2012Metric_Pad1.20x1.40mm_HandSolder
R4: 1k5; R_0805_2012Metric_Pad1.20x1.40mm_HandSolder
R8: 220k; R_0805_2012Metric_Pad1.20x1.40mm_HandSolder
R9: 47k; R_0805_2012Metric_Pad1.20x1.40mm_HandSolder
R11: 470k; R_0805_2012Metric_Pad1.20x1.40mm_HandSolder
R13: 22R; R_0805_2012Metric_Pad1.20x1.40mm_HandSolder
U1: LTC4054; TSOT-23-5
U2: STI3411A; TSOT-23-5
U5: XC6206PxxxMR; SOT-23-3

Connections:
#LOW_POWER_REQ: D44.1 (K); also elsewhere on the board
CHARGE_STATE: U1.1 (~CHRG); also elsewhere on the board
GND: BT1.2 (-), C1.2, C2.2, C3.2, C5.2, C22.2, D47.2 (A), Q2.2 (S), Q5.4 (G2), R4.1, R9.2, R11.1, U1.2 (GND), U2.2 (GND), U5.1 (GND); also elsewhere on the board
unnamed: BT1.1 (+), Q5.5 (D2), Q5.6 (D2), R1.1
unnamed: C22.1, D43.1 (K), Q5.1 (S1), R3.1, R7.1, U2.4 (VIN), U5.3 (VI)
unnamed: D44.2 (A), Q2.1 (G), R3.2, U2.1 (EN)
unnamed: D47.1 (K), R1.2
unnamed: Q1.1 (G), Q2.3 (D), Q3.1 (G), R7.2
unnamed: Q1.2 (S), Q5.3 (S2), Q5.7 (D1), Q5.8 (D1), U1.3 (BAT)
unnamed: Q3.3 (D), R13.1
unnamed: R4.2, U1.5 (PROG)
unnamed: R8.2, R9.1, U2.5 (FB)
unnamed: L1.1, U2.3 (LX)
VBAT: C3.1, Q1.3 (D); also elsewhere on the board
VBUS: C1.1, D43.2 (A), Q5.2 (G1), R11.2, U1.4 (V_{CC}); also elsewhere on the board
VDD: C2.1, C5.1, L1.2, R8.1, R13.2; also elsewhere on the board
VDD_AON: Q3.2 (S), U5.2 (VO); also elsewhere on the board

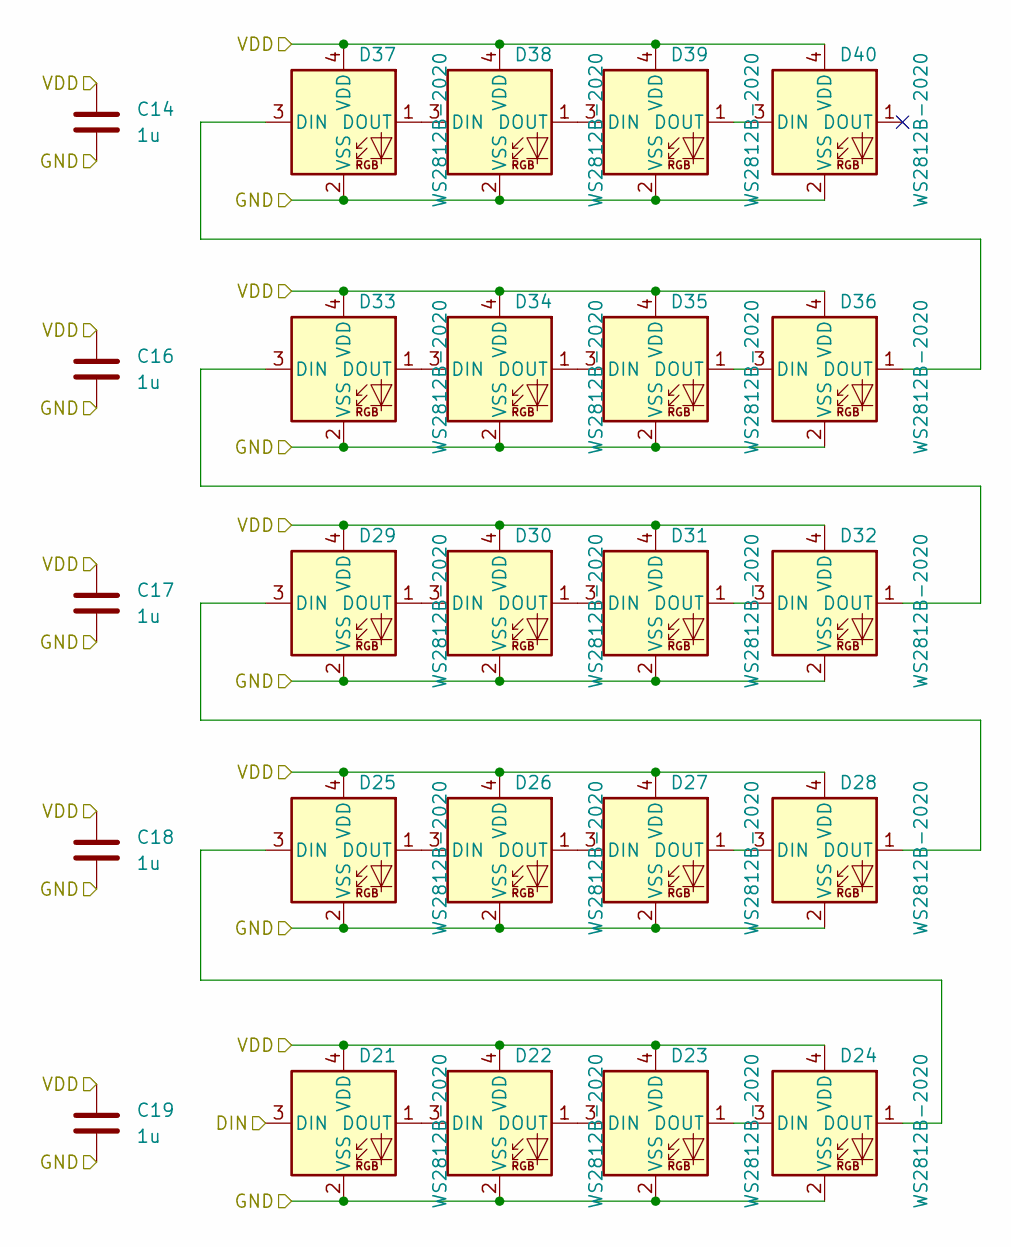
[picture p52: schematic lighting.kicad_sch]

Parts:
C14, C16, C17, C18, C19: 1u; C_0805_2012Metric_Pad1.18x1.45mm_HandSolder
D21, D22, D23, D24, D25, D26, D27, D28, D29, D30, D31, D32, D33, D34, D35, D36, D37, D38, D39, D40: WS2812B-2020; LED_WS2812B-2020_PLCC4_2.0x2.0mm

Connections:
/Main/LED_RETURN: D21.3 (DIN); also elsewhere on the board
GND: C14.2, C16.2, C17.2, C18.2, C19.2, D21.2 (VSS), D22.2 (VSS), D23.2 (VSS), D24.2 (VSS), D25.2 (VSS), D26.2 (VSS), D27.2 (VSS), D28.2 (VSS), D29.2 (VSS), D30.2 (VSS), D31.2 (VSS), D32.2 (VSS), D33.2 (VSS), D34.2 (VSS), D35.2 (VSS), D36.2 (VSS), D37.2 (VSS), D38.2 (VSS), D39.2 (VSS), D40.2 (VSS); also elsewhere on the board
unnamed: D21.1 (DOUT), D22.3 (DIN)
unnamed: D22.1 (DOUT), D23.3 (DIN)
unnamed: D23.1 (DOUT), D24.3 (DIN)
unnamed: D24.1 (DOUT), D25.3 (DIN)
unnamed: D25.1 (DOUT), D26.3 (DIN)
unnamed: D26.1 (DOUT), D27.3 (DIN)
unnamed: D27.1 (DOUT), D28.3 (DIN)
unnamed: D28.1 (DOUT), D29.3 (DIN)
unnamed: D29.1 (DOUT), D30.3 (DIN)
unnamed: D30.1 (DOUT), D31.3 (DIN)
unnamed: D31.1 (DOUT), D32.3 (DIN)
unnamed: D32.1 (DOUT), D33.3 (DIN)
unnamed: D33.1 (DOUT), D34.3 (DIN)
unnamed: D34.1 (DOUT), D35.3 (DIN)
unnamed: D35.1 (DOUT), D36.3 (DIN)
unnamed: D36.1 (DOUT), D37.3 (DIN)
unnamed: D37.1 (DOUT), D38.3 (DIN)
unnamed: D38.1 (DOUT), D39.3 (DIN)
unnamed: D39.1 (DOUT), D40.3 (DIN)
VDD: C14.1, C16.1, C17.1, C18.1, C19.1, D21.4 (VDD), D22.4 (VDD), D23.4 (VDD), D24.4 (VDD), D25.4 (VDD), D26.4 (VDD), D27.4 (VDD), D28.4 (VDD), D29.4 (VDD), D30.4 (VDD), D31.4 (VDD), D32.4 (VDD), D33.4 (VDD), D34.4 (VDD), D35.4 (VDD), D36.4 (VDD), D37.4 (VDD), D38.4 (VDD), D39.4 (VDD), D40.4 (VDD); also elsewhere on the board

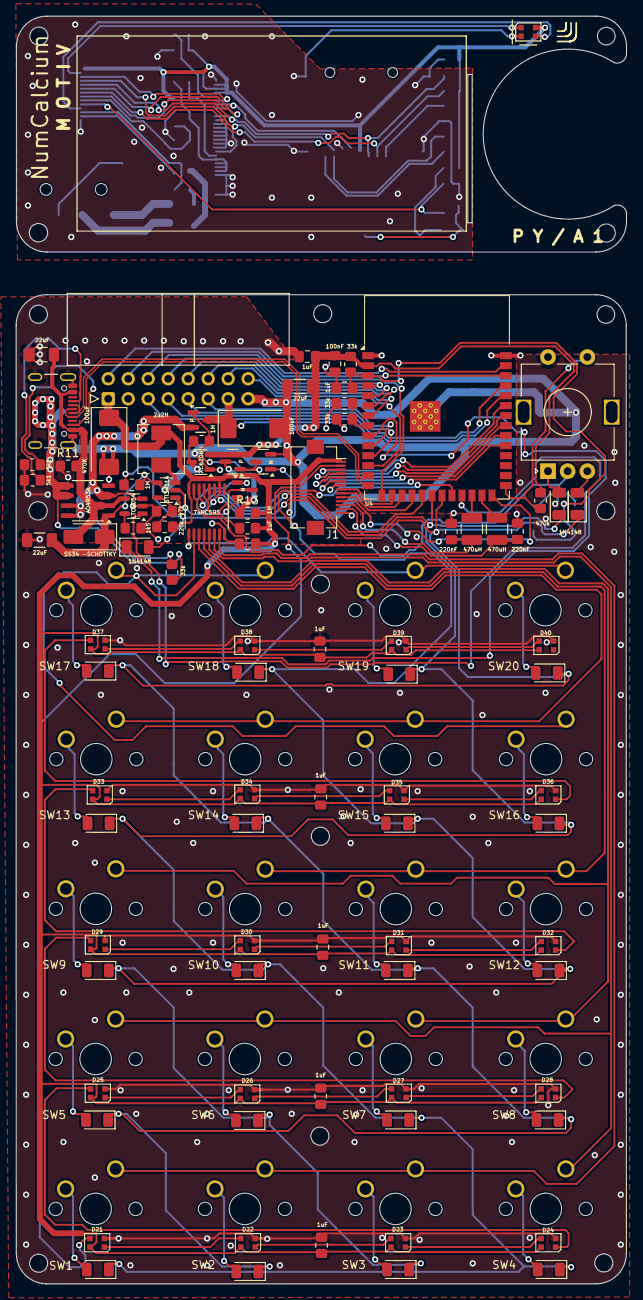
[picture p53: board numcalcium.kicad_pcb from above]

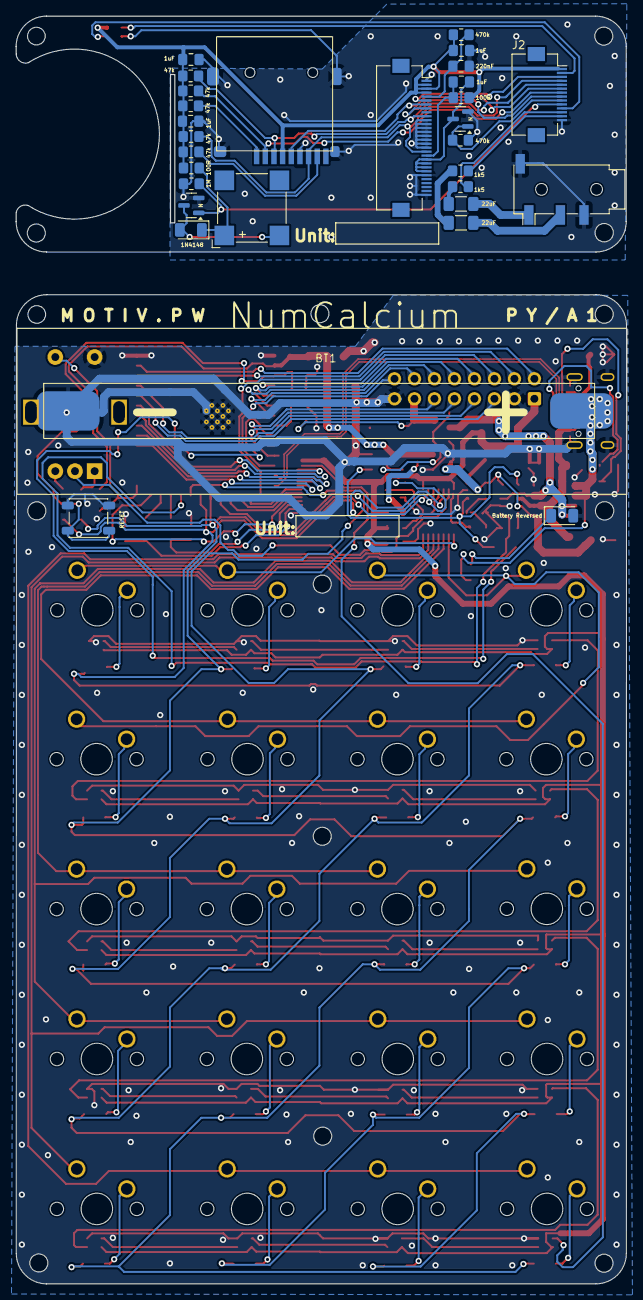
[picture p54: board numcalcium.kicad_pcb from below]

Board: 2 copper layers, 77.5 x 125.7 mm, 143 parts (30 on the bottom side), 129 nets.

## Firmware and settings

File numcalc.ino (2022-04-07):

//#include <Arduino.h>
//#include <U8g2lib.h>
//#include <SPI.h>
//#include <Wire.h>
//#include <Serial.h>
////
//U8G2_ST7565_ERC12864_ALT_F_4W_HW_SPI u8g2(U8G2_R0, /* cs=*/ PA4, /* dc=*/ PA3, /* reset=*/ PA2);
//
//SPIClass SPI_2(2);


// static uint8_t encoderLookup[256*3]={	0x92,0x49,0x24,0x92,0x49,0x26,0x92,0x49,0x34,0x92,0x49,0x36,0x92,0x49,0xA4,0x92,0x49,0xA6,0x92,0x49,0xB4,0x92,0x49,0xB6,0x92,0x4D,0x24,0x92,0x4D,0x26,0x92,0x4D,0x34,0x92,0x4D,0x36,0x92,0x4D,0xA4,0x92,0x4D,0xA6,0x92,0x4D,0xB4,0x92,0x4D,0xB6,0x92,0x69,0x24,0x92,0x69,0x26,0x92,0x69,0x34,0x92,0x69,0x36,0x92,0x69,0xA4,0x92,0x69,0xA6,0x92,0x69,0xB4,0x92,0x69,0xB6,0x92,0x6D,0x24,0x92,0x6D,0x26,0x92,0x6D,0x34,0x92,0x6D,0x36,0x92,0x6D,0xA4,0x92,0x6D,0xA6,0x92,0x6D,0xB4,0x92,0x6D,0xB6,0x93,0x49,0x24,0x93,0x49,0x26,0x93,0x49,0x34,0x93,0x49,0x36,0x93,0x49,0xA4,0x93,0x49,0xA6,0x93,0x49,0xB4,0x93,0x49,0xB6,0x93,0x4D,0x24,0x93,0x4D,0x26,0x93,0x4D,0x34,0x93,0x4D,0x36,0x93,0x4D,0xA4,0x93,0x4D,0xA6,0x93,0x4D,0xB4,0x93,0x4D,0xB6,0x93,0x69,0x24,0x93,0x69,0x26,0x93,0x69,0x34,0x93,0x69,0x36,0x93,0x69,0xA4,0x93,0x69,0xA6,0x93,0x69,0xB4,0x93,0x69,0xB6,0x93,0x6D,0x24,0x93,0x6D,0x26,0x93,0x6D,0x34,0x93,0x6D,0x36,0x93,0x6D,0xA4,0x93,0x6D,0xA6,0x93,0x6D,0xB4,0x93,0x6D,0xB6,0x9A,0x49,0x24,0x9A,0x49,0x26,0x9A,0x49,0x34,0x9A,0x49,0x36,0x9A,0x49,0xA4,0x9A,0x49,0xA6,0x9A,0x49,0xB4,0x9A,0x49,0xB6,0x9A,0x4D,0x24,0x9A,0x4D,0x26,0x9A,0x4D,0x34,0x9A,0x4D,0x36,0x9A,0x4D,0xA4,0x9A,0x4D,0xA6,0x9A,0x4D,0xB4,0x9A,0x4D,0xB6,0x9A,0x69,0x24,0x9A,0x69,0x26,0x9A,0x69,0x34,0x9A,0x69,0x36,0x9A,0x69,0xA4,0x9A,0x69,\
// 											0xA6,0x9A,0x69,0xB4,0x9A,0x69,0xB6,0x9A,0x6D,0x24,0x9A,0x6D,0x26,0x9A,0x6D,0x34,0x9A,0x6D,0x36,0x9A,0x6D,0xA4,0x9A,0x6D,0xA6,0x9A,0x6D,0xB4,0x9A,0x6D,0xB6,0x9B,0x49,0x24,0x9B,0x49,0x26,0x9B,0x49,0x34,0x9B,0x49,0x36,0x9B,0x49,0xA4,0x9B,0x49,0xA6,0x9B,0x49,0xB4,0x9B,0x49,0xB6,0x9B,0x4D,0x24,0x9B,0x4D,0x26,0x9B,0x4D,0x34,0x9B,0x4D,0x36,0x9B,0x4D,0xA4,0x9B,0x4D,0xA6,0x9B,0x4D,0xB4,0x9B,0x4D,0xB6,0x9B,0x69,0x24,0x9B,0x69,0x26,0x9B,0x69,0x34,0x9B,0x69,0x36,0x9B,0x69,0xA4,0x9B,0x69,0xA6,0x9B,0x69,0xB4,0x9B,0x69,0xB6,0x9B,0x6D,0x24,0x9B,0x6D,0x26,0x9B,0x6D,0x34,0x9B,0x6D,0x36,0x9B,0x6D,0xA4,0x9B,0x6D,0xA6,0x9B,0x6D,0xB4,0x9B,0x6D,0xB6,0xD2,0x49,0x24,0xD2,0x49,0x26,0xD2,0x49,0x34,0xD2,0x49,0x36,0xD2,0x49,0xA4,0xD2,0x49,0xA6,0xD2,0x49,0xB4,0xD2,0x49,0xB6,0xD2,0x4D,0x24,0xD2,0x4D,0x26,0xD2,0x4D,0x34,0xD2,0x4D,0x36,0xD2,0x4D,0xA4,0xD2,0x4D,0xA6,0xD2,0x4D,0xB4,0xD2,0x4D,0xB6,0xD2,0x69,0x24,0xD2,0x69,0x26,0xD2,0x69,0x34,0xD2,0x69,0x36,0xD2,0x69,0xA4,0xD2,0x69,0xA6,0xD2,0x69,0xB4,0xD2,0x69,0xB6,0xD2,0x6D,0x24,0xD2,0x6D,0x26,0xD2,0x6D,0x34,0xD2,0x6D,0x36,0xD2,0x6D,0xA4,0xD2,0x6D,0xA6,0xD2,0x6D,0xB4,0xD2,0x6D,0xB6,0xD3,0x49,0x24,0xD3,0x49,0x26,0xD3,0x49,0x34,0xD3,0x49,0x36,0xD3,0x49,0xA4,0xD3,0x49,0xA6,0xD3,0x49,0xB4,0xD3,0x49,0xB6,0xD3,0x4D,0x24,0xD3,0x4D,0x26,0xD3,0x4D,0x34,0xD3,\
// 											0x4D,0x36,0xD3,0x4D,0xA4,0xD3,0x4D,0xA6,0xD3,0x4D,0xB4,0xD3,0x4D,0xB6,0xD3,0x69,0x24,0xD3,0x69,0x26,0xD3,0x69,0x34,0xD3,0x69,0x36,0xD3,0x69,0xA4,0xD3,0x69,0xA6,0xD3,0x69,0xB4,0xD3,0x69,0xB6,0xD3,0x6D,0x24,0xD3,0x6D,0x26,0xD3,0x6D,0x34,0xD3,0x6D,0x36,0xD3,0x6D,0xA4,0xD3,0x6D,0xA6,0xD3,0x6D,0xB4,0xD3,0x6D,0xB6,0xDA,0x49,0x24,0xDA,0x49,0x26,0xDA,0x49,0x34,0xDA,0x49,0x36,0xDA,0x49,0xA4,0xDA,0x49,0xA6,0xDA,0x49,0xB4,0xDA,0x49,0xB6,0xDA,0x4D,0x24,0xDA,0x4D,0x26,0xDA,0x4D,0x34,0xDA,0x4D,0x36,0xDA,0x4D,0xA4,0xDA,0x4D,0xA6,0xDA,0x4D,0xB4,0xDA,0x4D,0xB6,0xDA,0x69,0x24,0xDA,0x69,0x26,0xDA,0x69,0x34,0xDA,0x69,0x36,0xDA,0x69,0xA4,0xDA,0x69,0xA6,0xDA,0x69,0xB4,0xDA,0x69,0xB6,0xDA,0x6D,0x24,0xDA,0x6D,0x26,0xDA,0x6D,0x34,0xDA,0x6D,0x36,0xDA,0x6D,0xA4,0xDA,0x6D,0xA6,0xDA,0x6D,0xB4,0xDA,0x6D,0xB6,0xDB,0x49,0x24,0xDB,0x49,0x26,0xDB,0x49,0x34,0xDB,0x49,0x36,0xDB,0x49,0xA4,0xDB,0x49,0xA6,0xDB,0x49,0xB4,0xDB,0x49,0xB6,0xDB,0x4D,0x24,0xDB,0x4D,0x26,0xDB,0x4D,0x34,0xDB,0x4D,0x36,0xDB,0x4D,0xA4,0xDB,0x4D,0xA6,0xDB,0x4D,0xB4,0xDB,0x4D,0xB6,0xDB,0x69,0x24,0xDB,0x69,0x26,0xDB,0x69,0x34,0xDB,0x69,0x36,0xDB,0x69,0xA4,0xDB,0x69,0xA6,0xDB,0x69,0xB4,0xDB,0x69,0xB6,0xDB,0x6D,0x24,0xDB,0x6D,0x26,0xDB,0x6D,0x34,0xDB,0x6D,0x36,0xDB,0x6D,0xA4,0xDB,0x6D,0xA6,0xDB,0x6D,0xB4,0xDB,0x6D,0xB6};

// uint16_t
//   numLEDs,       // Number of RGB LEDs in strip
//   numBytes;      // Size of 'pixels' buffer

// uint8_t
//   *pixels,        // Holds the current LED color values, which the external API calls interact with 9 bytes per pixel + start + end empty bytes
//   *doubleBuffer, // Holds the start of the double buffer (1 buffer for async DMA transfer and one for the API interaction.
//   rOffset,       // Index of red byte within each 3- or 4-byte pixel
//   gOffset,       // Index of green byte
//   bOffset,       // Index of blue byte
//   wOffset;       // Index of white byte (same as rOffset if no white)
// uint32_t
//   endTime;       // Latch timing reference
  
// void ws_begin(uint8_t n){
//   if(doubleBuffer) 
//   {
// 	  free(doubleBuffer); 
//   }

//   numBytes = (n<<3) + n + 2; // 9 encoded bytes per pixel. 1 byte empty peamble to fix issue with WS_SPI_DEV MOSI and on byte at the end to clear down MOSI 
// 							// Note. (n<<3) +n is a fast way of doing n*9
//   if((doubleBuffer = (uint8_t *)malloc(numBytes*2)))
//   {
//     numLEDs = n;	 
// 	pixels = doubleBuffer;
// 	// Only need to init the part of the double buffer which will be interacted with by the API e.g. setPixelColor
// 	*pixels=0;//clear the preamble byte
// 	*(pixels+numBytes-1)=0;// clear the post send cleardown byte.
// 	ws_clear();// Set the encoded data to all encoded zeros 
//   } 
//   else 
//   {
//     numLEDs = numBytes = 0;
//   }

//   SPI_2.setClockDivider(SPI_CLOCK_DIV16);// need bit rate of 400nS but closest we can do @ 72Mhz is 444ns (which is within spec)
//   SPI_2.begin();
// }

// void ws_setPixelColor(uint16_t n, uint8_t r, uint8_t g, uint8_t b)
//  {
//    uint8_t *bptr = pixels + (n<<3) + n +1;
//    uint8_t *tPtr = (uint8_t *)encoderLookup + g*2 + g;// need to index 3 x g into the lookup
   
//    *bptr++ = *tPtr++;
//    *bptr++ = *tPtr++;
//    *bptr++ = *tPtr++;

//    tPtr = (uint8_t *)encoderLookup + r*2 + r;
//    *bptr++ = *tPtr++;
//    *bptr++ = *tPtr++;
//    *bptr++ = *tPtr++;   
   
//    tPtr = (uint8_t *)encoderLookup + b*2 + b;
//    *bptr++ = *tPtr++;
//    *bptr++ = *tPtr++;
//    *bptr++ = *tPtr++;
//  }

// void ws_show(void) 
// {
//   SPI_2.dmaSendAsync(pixels,numBytes);// Start the DMA transfer of the current pixel buffer to the LEDs and return immediately.

//   // Need to copy the last / current buffer to the other half of the double buffer as most API code does not rebuild the entire contents
//   // from scratch. Often just a few pixels are changed e.g in a chaser effect
  
//   if (pixels==doubleBuffer)
//   {
// 	// pixels was using the first buffer
// 	pixels	= doubleBuffer+numBytes;  // set pixels to second buffer
// 	memcpy(pixels,doubleBuffer,numBytes);// copy first buffer to second buffer
//   }
//   else
//   {
// 	// pixels was using the second buffer	  
// 	pixels	= doubleBuffer;  // set pixels to first buffer
// 	memcpy(pixels,doubleBuffer+numBytes,numBytes);	 // copy second buffer to first buffer 
//   }	
// }

// void ws_clear() 
// {
// 	uint8_t * bptr= pixels+1;// Note first byte in the buffer is a preable and is always zero. hence the +1
// 	uint8_t *tPtr;

// 	for(int i=0;i< (numLEDs *3);i++)
// 	{
// 	   tPtr = (uint8_t *)encoderLookup;
//    	   *bptr++ = *tPtr++;
// 	   *bptr++ = *tPtr++;
// 	   *bptr++ = *tPtr++;	
// 	}
// }
//
//
//void setup(void) {
//  disableDebugPorts();
//  u8g2.begin();
//  u8g2.setContrast(80);
//  ws_begin(3);
//  
//}
//
//int i = 0 ;
//void loop(void) {
//  if(i&0x1){
//      int b = i<<2;
//      ws_setPixelColor(0,b,0,0);
//      ws_setPixelColor(1,0,b,0);
//      ws_setPixelColor(2,0,0,b);
//      ws_show();
//  }
//  
//  u8g2.clearBuffer();					// clear the internal memory
//  u8g2.setFont(u8g2_font_ncenB08_tr);	// choose a suitable font
//  u8g2.drawStr(i%30,i%30,"Hello World!");	// write something to the internal memory
//  u8g2.sendBuffer();					// transfer internal memory to the display
//  i++;
//  delay(100);  
//}

//calculator -> F1 = basic, F2 = sci, F3 = comp
//numpad -> F1 = normal, F2 = Arrows, F3 = phone ascii
//midi -> F1 = launchpad, F2 = seq usb, F3 = seq uart midi
//comms monitor -> F1 = UART, F2 = SPI, F3 = I2C
//GPIO -> F1 = debounced sw, F2 = clock bits program like cpld, F3 = PWM channels
//PWM audio -> F1 = osc, F2 scope, F3 nodes
//script ?

#include <MapleFreeRTOS900.h>
#include <Arduino.h>
#include <U8g2lib.h>
#include <SPI.h>
#include <Wire.h>
#include <Serial.h>
#include <USBComposite.h>
#include "defs.h"

U8G2_ST7565_ERC12864_ALT_F_4W_HW_SPI u8g2(U8G2_R0, /* cs=*/ LCD_CS, /* dc=*/ LCD_DC, /* reset=*/ LCD_RST);
SPIClass SPI_2(2);

USBHID HID;
HIDKeyboard Keyboard(HID);


typedef struct t_menu_item{
  char* text;
  void (*on_action)(void);
};

typedef struct t_menu {
  t_menu_item* items;
  uint8_t items_c;
  uint8_t items_i;
  uint8_t visible;
} cmenu;

typedef struct t_io {
  uint8_t target[4] = 0;
  uint8_t state = 0;
  uint8_t old_state = 0;
};

t_io io[20];
uint8_t enc_a, enc_b,enc_a_old,enc_b_old;
int8_t enc_turns, enc_turns_old;
uint8_t ok, oko;

uint8_t k = 0;
const uint8_t rows[5] = {ROW_A, ROW_B, ROW_C, ROW_D, ROW_E};
const uint8_t cols[4] = {SEG_A, SEG_B, SEG_C, SEG_D};

void setup(){
  disableDebugPorts();
  USBComposite.setProductId(0x0031);
  HID.begin(HID_KEYBOARD);
  Serial.begin(9600);

  io[13].target[0] = KEY_UP_ARROW;
  io[8].target[0] = KEY_LEFT_ARROW;
  io[9].target[0] = KEY_DOWN_ARROW;
  io[10].target[0] = KEY_RIGHT_ARROW;
  io[5].target[0] = KEY_UP_ARROW;
  io[0].target[0] = KEY_LEFT_ARROW;
  io[1].target[0] = KEY_DOWN_ARROW;
  io[2].target[0] = KEY_RIGHT_ARROW;

  for(int i=0; i<4; i++)
    pinMode(cols[i], INPUT_PULLDOWN);

  for(int i=0; i<6; i++)
    pinMode(rows[i], OUTPUT);

  pinMode(SYS_PDOWN, OUTPUT);
  digitalWrite(SYS_PDOWN, LOW);
  
  pinMode(LCD_LIGHT, OUTPUT);
  digitalWrite(LCD_LIGHT, HIGH);
  
  pinMode(B_OK,INPUT_PULLDOWN);
}

void loop(){
  ok = digitalRead(B_OK);
  if(ok != oko){
    oko = ok;
    if(!ok) return;

    if(cmenu != 1) cmenu = 1;

  }
  
  for(int r=0; r<5; r++){
    digitalWrite(rows[r],HIGH);
    for(int c=0; c<4; c++){
      int I = c + (r*4);
      if(io[I].target[cmode]){
        io[I].state = digitalRead(cols[c]);

        if(io[I].state && !io[I].old_state){
          Keyboard.press(io[I].target[cmode]);
        }
        else if(!io[I].state && io[I].old_state){
          Keyboard.release(io[I].target[cmode]);
        }
        
        if(io[I].state != io[I].old_state)
          io[I].old_state = io[I].state;
      }
    }
    digitalWrite(rows[r],LOW);
  }

  digitalWrite(ROW_F, HIGH);
  
    enc_a_old = enc_a;
    enc_b_old = enc_b;
    enc_a = digitalRead(SEG_A);
    enc_b = digitalRead(SEG_B);
    if(cmenu == 0) goto enc_clean;

    if(enc_a && !enc_b && !enc_a_old && !enc_b_old){
#ifdef DEBUG
      Serial.println("Right turn");
#endif
      
    }
    else if(!enc_a && enc_b && !enc_a_old && !enc_b_old){    
#ifdef DEBUG
      Serial.println("Left turn");
#endif
      
    }
  
enc_clean:
  digitalWrite(ROW_F, LOW);

  delay(5);
}

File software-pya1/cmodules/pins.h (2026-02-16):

#ifndef BOARD_PINS_H
#define BOARD_PINS_H


// py-a0
//#define BOARD_PIN_LCD_CS    42
//#define BOARD_PIN_SD_CS     38
//#define BOARD_PIN_LCD_DC    45

//#define BOARD_PIN_LEDS      47
//#define BOARD_PIN_LCD_LED   46
//#define BOARD_PIN_BUZZER    21
//#define BOARD_PIN_A_OUT_L   43
//#define BOARD_PIN_A_OUT_R   44

//Internal
#define BOARD_PIN_LCD_CS    42
#define BOARD_PIN_SD_CS     38
#define BOARD_PIN_LCD_DC    46

#define BOARD_PIN_LEDS      45
#define BOARD_PIN_LCD_LED   9

#define BOARD_PIN_BUZZER    10
#define BOARD_PIN_A_OUT_L   47
#define BOARD_PIN_A_OUT_R   48


#define BOARD_PIN_SLEEP_REQ 16
#define BOARD_PIN_VBAT_MON  15
#define BOARD_PIN_CHR_STATE 21


#define BOARD_PIN_CK        39
#define BOARD_PIN_MOSI      40
#define BOARD_PIN_MISO      41

#define BOARD_PIN_RX1       18
#define BOARD_PIN_TX1       17
#define BOARD_PIN_RX0       44
#define BOARD_PIN_TX0       43

//Port plug
#define BOARD_PIN_PORT1     1
#define BOARD_PIN_PORT2     2
#define BOARD_PIN_PORT3     3
#define BOARD_PIN_PORT4     4
#define BOARD_PIN_PORT5     5
#define BOARD_PIN_PORT6     6
#define BOARD_PIN_PORT7     7
#define BOARD_PIN_PORT8     8

#define BOARD_PIN_PORT9     17
#define BOARD_PIN_PORT10    18
#define BOARD_PIN_PORT11    43
#define BOARD_PIN_PORT12    44

#define BOARD_PIN_PORT_SCL  18
#define BOARD_PIN_PORT_SDA  17

// IO keypad + encoder
#define BOARD_PIN_IO_OE     11
#define BOARD_PIN_IO_CK     12
#define BOARD_PIN_IO_DD     13
#define BOARD_PIN_IO_TT     14
#define BOARD_PIN_B_OK      0

#endif //BOARD_PINS_H

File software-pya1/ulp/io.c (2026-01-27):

#include <stdio.h>
#include <stdint.h>
#include <stdbool.h>
#include "ulp_riscv.h"
#include "ulp_riscv_gpio.h"
#include "ulp_riscv_utils.h"

#define PIN_CK 12
#define PIN_DD 13
#define PIN_LT 11
#define PIN_TT 14

int var_turns;
static unsigned int rscan;

static unsigned int pscan;
static unsigned int pscan_old;
unsigned int var_bscan;
unsigned int var_bdown;
unsigned int var_bup;
unsigned int var_bok;
unsigned int var_bhome;
int var_ulp_tick = 0;

void shiftOut(unsigned int v){

    ulp_riscv_gpio_input_disable(PIN_CK);
    ulp_riscv_gpio_input_disable(PIN_DD);
    ulp_riscv_gpio_output_enable(PIN_CK);
    ulp_riscv_gpio_output_enable(PIN_DD);

    ulp_riscv_gpio_output_level(PIN_CK, 0);
    ulp_riscv_gpio_output_level(PIN_DD, 0);
    
    ulp_riscv_gpio_output_level(PIN_LT, 0);
    for(int i=0; i<8; i++){
        ulp_riscv_gpio_output_level(PIN_DD, v & (1<<i));
        ulp_riscv_gpio_output_level(PIN_CK,1);
        ulp_riscv_gpio_output_level(PIN_CK,0);
    }
    ulp_riscv_gpio_output_level(PIN_LT, 1);
}

unsigned int readPins(){
    
    ulp_riscv_gpio_output_disable(PIN_CK);
    ulp_riscv_gpio_output_disable(PIN_DD);
    ulp_riscv_gpio_input_enable(PIN_CK);
    ulp_riscv_gpio_input_enable(PIN_DD);

    return (ulp_riscv_gpio_get_level(PIN_TT) << 2) 
        | (ulp_riscv_gpio_get_level(PIN_DD) << 1) 
        | (ulp_riscv_gpio_get_level(PIN_CK) << 0);
}


int main (void)
{    
    var_bok = !ulp_riscv_gpio_get_level(0);
    var_bhome |= var_bok;

    ulp_riscv_gpio_init(PIN_CK);
    ulp_riscv_gpio_init(PIN_DD);
    ulp_riscv_gpio_init(PIN_LT);
    ulp_riscv_gpio_init(PIN_TT);
    ulp_riscv_gpio_input_enable(PIN_TT);
    ulp_riscv_gpio_pulldown(PIN_TT);
    ulp_riscv_gpio_pulldown(PIN_CK);
    ulp_riscv_gpio_pulldown(PIN_DD);

    ulp_riscv_gpio_output_enable(PIN_LT);
    
    pscan_old = pscan;
    pscan = 0;
    for(int jj=0; jj<7; jj++){
        shiftOut(1<<jj);
        pscan |= (readPins() << (jj * 3));
        
    }
    var_bup |= (pscan_old & (~pscan)) & 0xFFFFF;
    var_bdown |= (pscan & (~pscan_old)) & 0xFFFFF;   
    var_bscan = pscan; 

    shiftOut(1<<7);
    rscan = ((rscan<<2) | readPins()) & 0xF;
    if(rscan == 0b1011) {
        if(var_turns > 0) var_turns = 0;
        var_turns--;    
    }
    if(rscan == 0b0111) {
        if(var_turns < 0) var_turns = 0;
        var_turns++;    
    }

    ulp_riscv_gpio_input_disable(PIN_CK);
    ulp_riscv_gpio_input_disable(PIN_DD);
    ulp_riscv_gpio_input_disable(PIN_TT);
    ulp_riscv_gpio_input_disable(PIN_LT);
    ulp_riscv_gpio_output_disable(PIN_CK);
    ulp_riscv_gpio_output_disable(PIN_DD);
    ulp_riscv_gpio_output_disable(PIN_TT);
    ulp_riscv_gpio_output_disable(PIN_LT);
    ulp_riscv_gpio_deinit(PIN_CK);
    ulp_riscv_gpio_deinit(PIN_DD);
    ulp_riscv_gpio_deinit(PIN_LT);
    ulp_riscv_gpio_deinit(PIN_TT);
    
    var_ulp_tick += 1;
    return 0;
}

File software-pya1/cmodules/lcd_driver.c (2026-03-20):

#include "font.h"
#include "font_hex_codes.h"
#include "vt100.h"
#include "board.h"

uint8_t lineBuf[1024*2];
SemaphoreHandle_t spi_semaphore;
QueueHandle_t buffer_queue;


// Utility functions
void driver_send_cmd(uint8_t cmd) {
    gpio_set_level(BOARD_PIN_LCD_DC, 0); // Command mode
    spi_transaction_t t = {
        .length = 8,
        .tx_buffer = &cmd
    };
    spi_device_polling_transmit(lcdspi_handle, &t);
}

void driver_send_data(uint8_t data) {
    gpio_set_level(BOARD_PIN_LCD_DC, 1); // Data mode
    spi_transaction_t t = {
        .length = 8,
        .tx_buffer = &data
    };
    spi_device_polling_transmit(lcdspi_handle, &t);
}

void driver_start_pixel(){
    gpio_set_level(BOARD_PIN_LCD_DC, 1); // Data mode
}
void driver_send_pixel_data(const void* pixel, uint32_t bits){
    spi_transaction_t t = {
        .length = bits,
        .tx_buffer = pixel
    };
    spi_device_polling_transmit(lcdspi_handle, &t);
}
void driver_end_pixel(){
}

void driver_setup(){
    driver_send_cmd(0x01);  // Software reset
    driver_send_cmd(0x11);  // Sleep out

    driver_send_cmd(0x36);  // Memory data access control (MADCTL)
    driver_send_data(0x60); // Row/column swap, RGB order

    driver_send_cmd(0x3A);  // Pixel format
    driver_send_data(0x05); // 16 bits per pixel
    
    driver_send_cmd(0x21); 

    driver_send_cmd(0x13);  // Normal display mode on
    driver_send_cmd(0x29);  // Display on
}

void driver_init() {
    // Configure backlight, CS, DC, and Reset pins
    gpio_config_t io_conf = {
        .pin_bit_mask =  (1ULL << BOARD_PIN_LCD_DC),
        .mode = GPIO_MODE_OUTPUT
    };
    gpio_config(&io_conf);
    
    driver_setup();
    driver_fill(0,0,X_SIZE,Y_SIZE, 0,NULL);
}

void driver_fill(int16_t x, int16_t y, int16_t w, int16_t h, uint16_t color, uint16_t* canvas){
    if(x >= X_SIZE) return;
    if(y >= Y_SIZE) return;
    if(x < 0) {
        w -= x;
        x = 0;
    }
    if(y < 0) {
        h -= y;
        y = 0;
    }
	if(w > X_SIZE) w = X_SIZE;
	if(h > Y_SIZE) h = Y_SIZE;

    int xx = x;
    int xw = x + w;
    int yy = y;
    int yh = y + h;

    if(canvas){
        for(int iy=yy; iy<yh; iy++){
            for(int ix=xx; ix<xw; ix++){
                driver_pixel(ix,iy,color,canvas);
            }
        }
        return;
    }

    xw -= 1;
    yh -= 1;

    driver_send_cmd(0x2A); 
    driver_send_data((xx & 0x100) >> 8); driver_send_data(xx & 0xff); 
    driver_send_data((xw & 0x100) >> 8); driver_send_data(xw & 0xff); 

    driver_send_cmd(0x2B); 
    driver_send_data(0x00); driver_send_data(yy + Y_OFFSET);
    driver_send_data(0x00); driver_send_data(yh + Y_OFFSET); 

    driver_send_cmd(0x2C); 
	
	uint32_t c0 = (color & 0xFF);
	uint32_t c1 = (color & 0xFF00) >> 8;

    uint32_t xferred = 0;
    uint32_t size = w*h;
    driver_start_pixel();
    do{
        int count = size - xferred;
        uint8_t *buf = (uint8_t*)lineBuf;
        if(count > 1024) count = 1024;
        for (int i = xferred; i < count*2; i+=2) {
            buf[i] = c1;
            buf[i+1] = c0;
        }
        driver_send_pixel_data(lineBuf,count*16);
        xferred += count;
    }while(xferred != size);
    driver_end_pixel();
}

void driver_pixel(int16_t x, int16_t y, uint16_t color, uint16_t* canvas) {
    if(canvas){
        uint32_t c0 = (color & 0xFF);
        uint32_t c1 = (color & 0xFF00) >> 8;

        int ii = (x + y*X_SIZE);
        canvas[ii] = c1 + (c0<<8);
        return;
    }

    int xx = x;
    int xw = x;
    int yy = y;
    int yh = y;
    driver_send_cmd(0x2A); 
    driver_send_data((xx & 0x100) >> 8); driver_send_data(xx & 0xff); 
    driver_send_data((xw & 0x100) >> 8); driver_send_data(xw & 0xff); 

    driver_send_cmd(0x2B); 
    driver_send_data(0x00); driver_send_data(yy + Y_OFFSET);
    driver_send_data(0x00); driver_send_data(yh + Y_OFFSET); 

    driver_send_cmd(0x2C);
    driver_send_data(color >> 8); 
    driver_send_data(color & 0xFF);
}


bool driver_ansiIsLeft(const unsigned char* text, int *ii, int *count) {
    if (text[0] == '\033') { 
        int index = 1; 
        int chars = 0;

        if (text[index] == '[') { 
            index++;

            if (!(text[index] >= '0' && text[index] <= '9')) {
                return false;
            }

            while (text[index] >= '0' && text[index] <= '9') {
                chars = chars * 10 + (text[index] - '0');
                index++;
            }

            if (text[index] == 'D') {
                *ii = index + 1;  
                *count = chars;   
                return true;
            }
        }
    }
    return false;
}


bool driver_ansiIsErase(const unsigned char* text, int *ii){
	if(text[0] == '\033'){
		bool erase = text[1] == '[' && text[2] == 'K';
        if(erase)
            *ii += 2;
        return erase;
	}
	return false;
}


void driver_print_font_value(unsigned char ch, uint16_t *buf, uint8_t scale, uint16_t bg, uint16_t color, int font_wide, int font_tall, uint8_t *font_buf, int x_off, int y_off){

    uint8_t bytes_per_height = (font_tall/8+1);
    uint32_t charStart = ch * font_wide;

    uint16_t ws = font_wide * scale;
    uint16_t lws = ws;

    if(x_off != -1 && y_off != -1){
        color = ((color & 0xFF)<<8) + ((color&0xFF00)>>8);
        lws = X_SIZE;
    }
    else{
        x_off = 0;
        y_off = 0;
    }
    
    for(int xx=0; xx<font_wide; xx++){
        for(int yy=0; yy<font_tall; yy++){
            uint16_t cc = bg;
            uint8_t b = font_buf[(xx + charStart)*bytes_per_height + (yy/8)];
            if(b & (1<<(yy%8)))
                cc = color;
            
            uint16_t sx = (xx * scale);
            uint16_t sy = (yy * lws * scale);
            for(int iy=0; iy<scale; iy++){
                for(int ix=0; ix<scale; ix++)
                    buf[sx+ix+x_off + (y_off*lws)+sy+(iy*lws)] = cc;
            }
        }
    }
}
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

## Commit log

2022-04-07 pin defs and schematic
2022-04-08 todo - confilcting spi miso pin with lcd
2022-04-19 working hw test + defs fix
    [numcalc.ino]
2022-04-19 fixed include paths on main machine, fixing eeprom last program used index
    [numcalc.ino]
2022-04-20 eeprom last prog fix
    [numcalc.ino]
2022-04-20 font change and compile fix
    [numcalc.ino]
2022-04-20 remove RTOS, screen update on button press. to fix 3 button press to go to prog sel from dark screen
    [numcalc.ino]
2022-04-20 correct refresh, now with force refresh flag in stats
    [numcalc.ino]
2022-04-21 UART log screen
2022-04-23 auto poweroff 20mins
2022-04-24 closer to inputting numbers correctly
    [numcalc.ino]
2022-05-01 vnum_t insert and delete digits
2022-06-24 font source include for arduino
2022-06-24 keypad working again
    need to thing about fixing usb init transitior missing and auto connection
    [numcalc.ino]
2022-06-26 updated hw drivers
2022-06-26 i2s scanner, suspected hw issue
    [numcalc.ino]
2022-06-28 drawtile drivers
2022-06-29 untested port of calc with new lcd driver
2022-06-29 functional calculator, broken sig digit print
2022-07-03 basic i2c comms
2022-07-03 comms i2c imode selectors
2022-07-03 temp work around for cmenu, need to fix usb
    [numcalc.ino]
2022-07-31 gpio: +adc +pwm screen
2022-08-09 scope: compilation typo fix
    [numcalc.ino]
2022-08-09 scope: works with audio sig, to fix screen tearing
    [numcalc.ino]
2022-08-10 OD pins and 50kHz clock for charge pump testing
2022-08-13 working scope but struggles to pick up 50hz finger
2022-08-13 trigger filter
2022-08-20 scope: disabled charge pump clock
2022-08-21 calc: QoL to be tested
    +auto replace symbol +auto insert multiply inbetween number and function +doubleFromNumber()
    [numcalc.ino]
2022-12-16 [main] UART MIDI out (fix for midi cc)
    [numcalc.ino]
2023-02-20 [main] archive software before RC1 board rework
2024-03-19 [mp32][wip] import schematic and ulp files so far :)
    [inputs.kicad_sch, numcalcium.kicad_pcb, numcalcium.kicad_sch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]
2024-12-10 [py] add hardware designs for esp32 and S3, micropython submodule added
    [CPU.kicad_sch, Cherry MX.STEP, EC11_Rotary_Encoder_Switched.step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]
2024-12-26 [dev] py-a0 board files
    [main.kicad_sch, numcalcium.kicad_pcb, untitled.kicad_sch]
2025-01-08 hardware: py/a0 revision 1.1 using FFC connectors
    [Kailh Hotswap MX v22.step, beschr. Kappe.step, lighting.kicad_sch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]
2025-01-08 board: sd card module and lcd compatibility
2025-01-12 terminal:os.dupterm Stream support
    move files and rename folders to board_src and scripts
    [numcalcium.kicad_pcb, power.kicad_sch, untitled.kicad_sch]
2025-01-17 board: terminal and SD singleton and reinitalizaton fixes
    [board_sdcard.c, display_bmp.py, io.c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]
2025-01-24 board: mpy loader in progress
2025-01-24 hw: power management begin
    [main.kicad_sch, power.kicad_sch]
2025-01-24 hw: py-a0 schematic
2025-01-26 hw: testing power switch solution
    [power.kicad_sch]
2025-02-04 hw: py-a1 board revision
    [CPU.kicad_sch, Cherry MX.STEP, EC11_Rotary_Encoder_Switched.step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]
2025-02-04 hw: devlog screenshots esp32 -> pya1
2025-02-08 hw: passives values simpler, tantlum caps, silkscreen tweaks
    [front.kicad_sch, main.kicad_sch, numcalcium.kicad_pcb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]
2025-02-08 board: lcd singleton fix for soft reset
2025-02-08 board: singleton fix for SD soft reset
    [board_sdcard.c]
2025-02-08 board: keys and nav modules for board io
2025-02-08 board: rename board_src- > pya1
2025-02-08 board: remove old tests
2025-02-08 board: update submodule to own fork of micropython
2025-02-08 board: add board pin definitions and auto-gen pins.csv, pins.py
2025-02-08 board: preparation for pya1
2025-02-08 board-hw: pya1 schematic pdf
    [front.kicad_sch, lighting.kicad_sch, main.kicad_sch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]
2025-02-11 board: ble + usb keypad driver code
2025-02-14 board: closer to fiinal board module
    investigating sdm multiple phantom channels
2025-02-17 board: provisional program launcher
2025-02-20 hw: fixes for py-a1
    [front.kicad_sch, numcalcium.kicad_pcb, numcalcium.kicad_sch]
2025-02-20 board: test for py-a1
2025-02-21 board: dual buffer dac tuple argument
2025-02-21 board: audio streaming test with some crackle on sine wave buffer boundary
    [audio.py]
2025-02-21 board: io tests for py-a1
2025-02-23 board: DAC module done with __del__ finaliser
    keys.py now allows keys == keys.KEY_* for quick checking
2025-02-24 hw: pya1 schematic rearange and post assembly test for inputs
    [front.kicad_sch, main.kicad_sch, numcalcium.kicad_pcb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]
2025-02-24 all: rearange folders and restrucutre layout
    [CPU.kicad_sch, Cherry MX.STEP, EC11_Rotary_Encoder_Switched.step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]
2025-02-25 tests: shorted pins self-test and power-stress test adjust
2025-02-26 board: work on mpy loader and adjustments on program loader
2025-02-27 board: more advancements for cart loading from stream and mem on real EEPROM
2025-02-28 board: bmp natmod, delete old cmodules
2025-03-01 board: lcd double buffering support and SPI max speed enabled
2025-03-03 board: lcd.parseBMP from natmode bmp
2025-03-04 board: board_lcd split int o driver and bmp parts
2025-03-04 board: lcd color fill fix and tests for double-buffer then fill (failing)
    [lcd_driver.c]
2025-03-04 board: revert to non-doublebuffer screen
    helper task filler as it was too problematic on reload/soft-reset
    [lcd_driver.c]
2025-03-04 board: proper lcd.print() like python's
    fixed comma character in font for lcd
2025-03-05 launcher: crash screen (OSOD) launcher: faster program picker board: rgb and html notation color support for LCD
2025-03-05 board: lcd cursor can use floats for position
2025-03-06 tests: battery charge/discharge
2025-03-07 board: LCD.print will show escape character hex codes in the space of one character
2025-03-07 board: fix LCD ansi escape ESC[#D
    [lcd_driver.c]
2025-03-08 board: lcd exclusivity using board.LCD.__lock, can use _board.Terminal in a separate thread font: easier font generation and allow of selecting font at build time
2025-03-12 board: lcd.options support for html and rgb color tuples. tests: inputs show keysDown
2025-03-12 board: cartrige.py for loading cartrige code
2026-01-23 build: docker builds + update MP version to RV builds
    [pins.csv]
2026-01-23 drivers: updated `board` module to be easier to use and more compact
2026-01-23 test: updated tests to run on new `board` module
2026-01-23 dev-test: updated some test modules to run on new `board` module
2026-01-23 board: battery and low power mode beginnings
2026-01-24 board: fixes for singleton object equality and crash prevention
    [board_dac.c, board_sdcard.c, modboard.c]
2026-01-24 board: more robust io dirver for encoder missing turns. bug: account for new .ld output in ulp gen
    [io.c]
2026-01-27 all: fix sleep in sw and hw but hw layout prevents keyscanning in sleep Need to find a way to sniff GPIO0 in sleep
    [numcalcium.kicad_pcb, power.kicad_sch]
2026-01-27 board: low power sleep wake on gpio0, little glitch which resets board again on exitLowPower() due to bug in hw design with regulators
    [io.c]
2026-01-28 pcb: redesign fix for LowPowerReq - added passives optional cap for slowstart on regulator switching to hi-power
    [front.kicad_sch, lighting.kicad_sch, main.kicad_sch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]
2026-01-28 board: allow tracking generated files
2026-01-28 all: update readme + module rename update module `board` and rename to `numcalc`
2026-02-16 board: custom font loading
2026-02-16 board: basic cartrige code loading confirmed
    [pins.csv]
2026-02-16 all: clean debug prints
2026-02-16 modules: added home button exclusivity flag
2026-02-16 pcb: revert led path to allow the option of populating rgb keys or not
    [numcalcium.kicad_pcb, power.kicad_sch]
2026-03-15 lcd: support no autowrap for printing strings as a simple graphic primitive instead of emulating terminal behaviour
2026-03-20 lcd: font unload mem leak bugfix
    [font.py, numcalc.py]
2026-03-23 lcd: bottom up cursor bugfix
    [numcalc.py]
